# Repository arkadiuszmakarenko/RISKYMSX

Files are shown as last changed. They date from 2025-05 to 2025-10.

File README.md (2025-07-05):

# RISKYMSX

The RISKYMSX cartridge by Arkadiusz Makarenko is a compact MSX flash ROM cartridge based on the inexpensive CH32V30xVCT6 RISC-V MCU which can be easily programmed from a MSX computer using a FAT formatted USB pen drive containing ROM files.

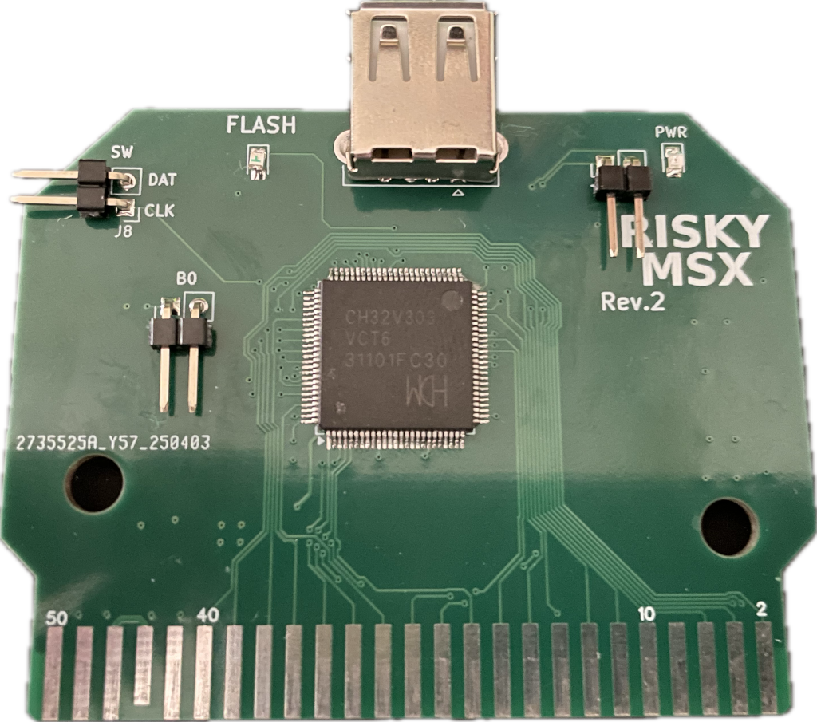
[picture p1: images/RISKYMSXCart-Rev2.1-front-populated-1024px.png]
[](images/RISKYMSXCart-Rev2.1-front-populated-1024px.png)

## Main Features

* Support for up to 256KB ROMs
* SCC emulation
* Firmware updates using a USB-A cable (or alternatively a WCH-LinkE programmer)
* ROM Flashing:
  * No external flash programmer is needed
  * A ROM can be flashed in-system using a MSX computer and a FAT-formatted USB pen drive
  * `ROM Flashing Mode` is activated by pressing GRAPH key during MSX boot
  * Automatic flashing of ROMs from USB can be achieved via specially named ROM archives
  * Manually flashing of ROMs from USB is done using a simple interactive menu
  * FAT long filenames are supported
* Supported mappers:
  * Standard 16KB ROMs
  * Standard 32KB ROMs
  * Standard 48KB /64KB ROMs
  * KONAMI without SSC
  * KONAMI with SSC (EN - SCC emulation enabled)
  * KONAMI with SSC (DIS - SCC emulation disabled)
  * ASCII 8K
  * ASCII 16K
  * Neo 8k
  * Neo 16k

## Hardware

The RISKYMSX cartridge is made up of a 4-layer PCB with a reduced set of SMD components and through-hole connectors:
* A WCH [CH32V303VCT6](https://www.wch-ic.com/products/CH32V303.html) MCU (or alternatively a [CH32V307VCT6](https://www.wch-ic.com/products/CH32V307.html))
* Two LEDs, one to indicate power on state, and one lit during `ROM Flashing Mode`
* A [LM1117](https://www.ti.com/lit/ds/symlink/lm1117.pdf) voltage regulator to provide +3V3 to the MCU from the +5V rail of the MSX cartridge slot
* A [MCP6001](https://ww1.microchip.com/downloads/aemDocuments/documents/MSLD/ProductDocuments/DataSheets/MCP6001-1R-1U-2-4-1-MHz-Low-Power-Op-Amp-DS20001733L.pdf) operational amplifier to enhance the SCC audio signal fed into the MSX cartridge SOUNDIN pin
* Three headers:
  * B0: open by default, closed only while programming the MCU using the `WCHISPTool_CMD` tool
  * DAT/CLK: unconnected by default, used to program the MCU using the [`WCH-LinkE`](https://www.wch-ic.com/products/WCH-Link.html) programmer via SWDIO/SWCLK
  * RX/TX: unconnected by default, serial debug console
* One USB Type-A female connector
* Several passives required for proper operation of the above components

### Revisions

There are several hardware revisions of the cartridge. The main ones are listed here in reverse chronological order.

#### Rev 2.1 (current)

This version introduces the following changes:
* the flash button is removed, as the flashing interface can be accessed by pressing the GRAPH key on the MSX keyboard during boot
* unnecessary leds are removed, leaving just the Flash and Power leds
* the audio amplifier circuit is enhanced with a low pass filter 

See the [Bill Of Materials (BoM)](https://html-preview.github.io/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) generated from the KiCad files for information about the specific components used.

Have a look at the [schematic and PCB](https://kicanvas.org/?github=https%3A%2F%2Fgithub.com%2Farkadiuszmakarenko%2FRISKYMSX%2Ftree%2Fmain%2Fboard) using [KiCanvas](https://kicanvas.org).

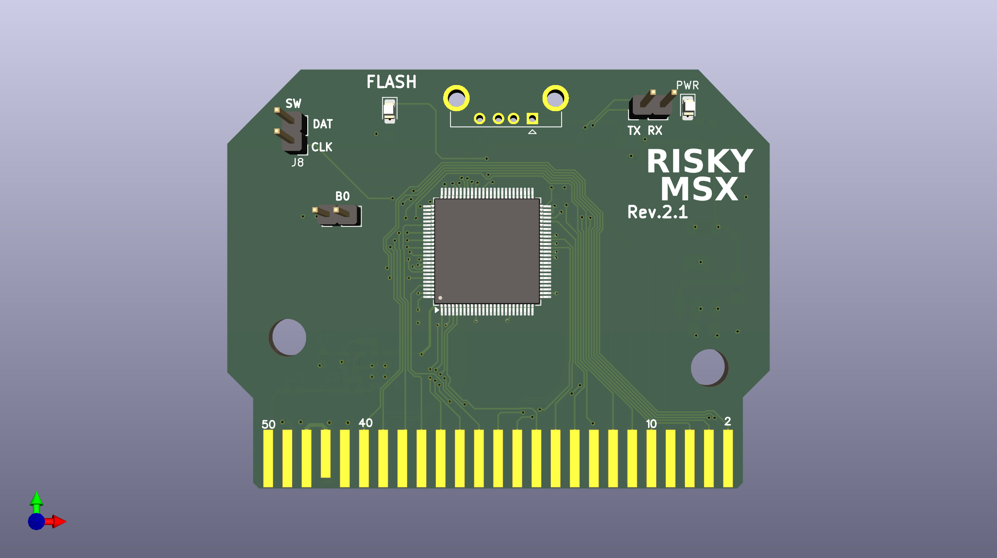
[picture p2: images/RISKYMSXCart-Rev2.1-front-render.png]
[](images/RISKYMSXCart-Rev2.1-front-render.png)
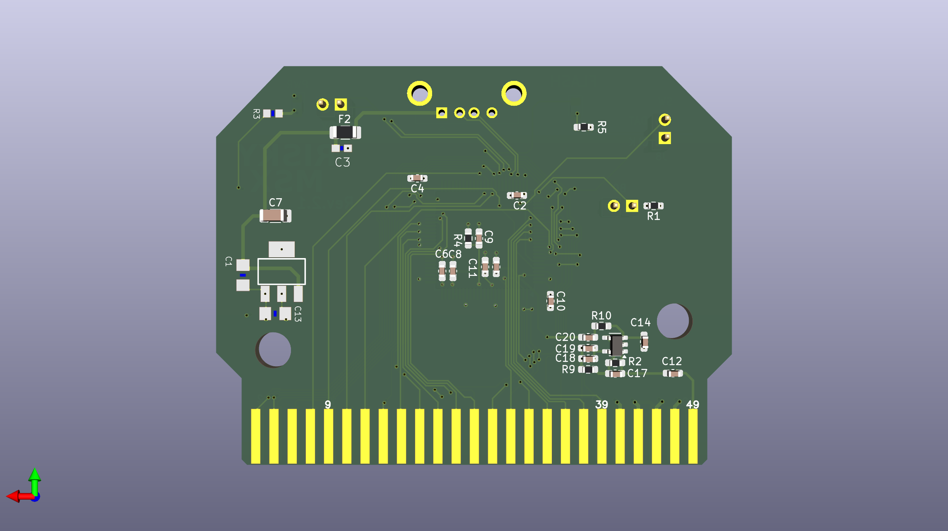
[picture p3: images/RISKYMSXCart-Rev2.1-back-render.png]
[](images/images/RISKYMSXCart-Rev2.1-back-render.png)

#### Rev 2 (obsolete)

This version introduces the following changes:
* the LM1117 voltage regulator and related passives are moved to the back of the PCB
* the B1 header is removed as it has no practical use
* a simple audio amplifier circuit is added for SCC sound

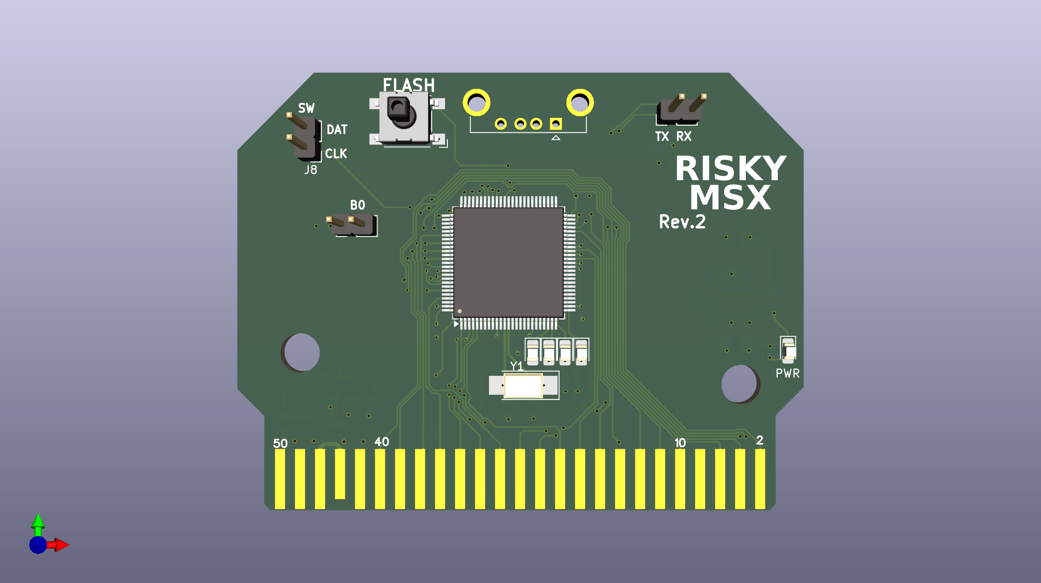
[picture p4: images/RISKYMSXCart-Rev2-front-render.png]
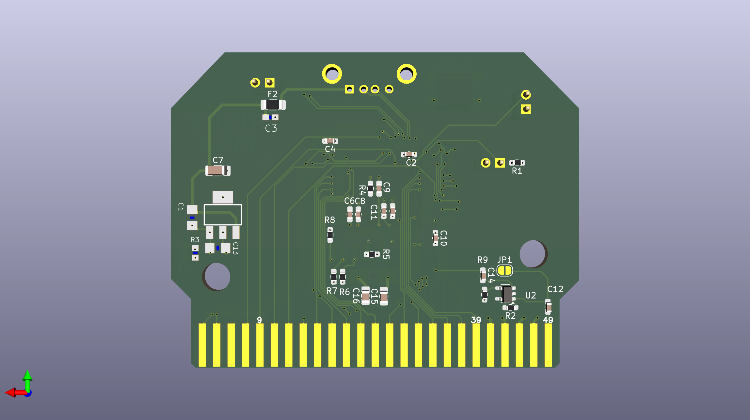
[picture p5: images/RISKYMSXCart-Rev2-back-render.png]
[](images/RISKYMSXCart-Rev2-front-render.png)|[](images/RISKYMSXCart-Rev2-back-render.png)
|-|-|
|RISKYMSX Rev 2 front render|RISKYMSX Rev 2 rear render|

#### Rev 1 (obsolete)

This is the initial revision of the RISKYMSX cartridge.

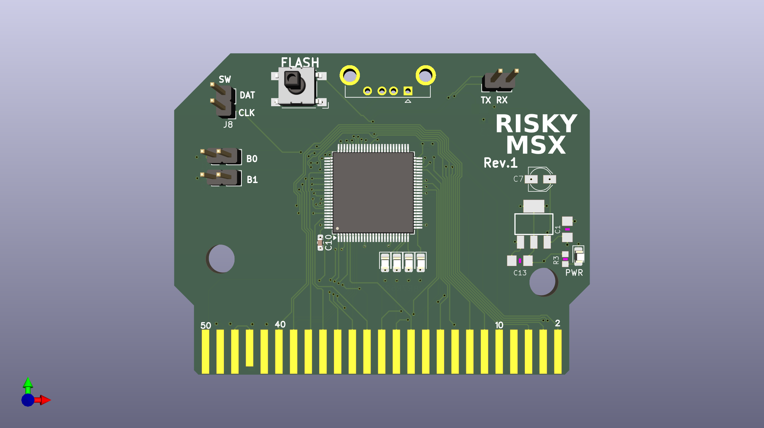
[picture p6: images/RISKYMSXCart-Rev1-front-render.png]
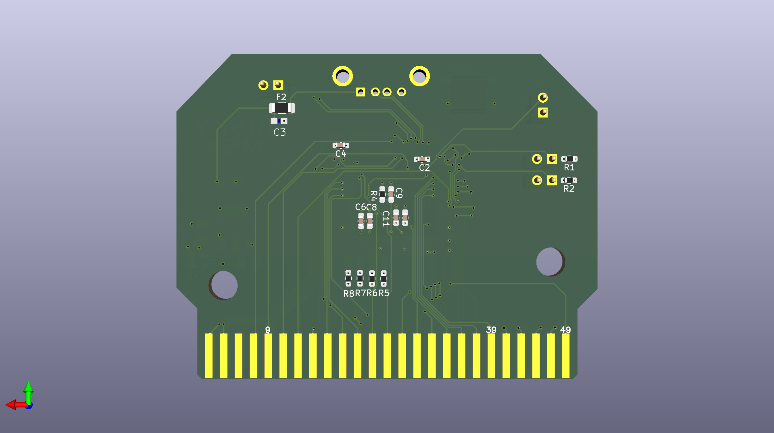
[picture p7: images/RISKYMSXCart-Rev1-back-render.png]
[](images/RISKYMSXCart-Rev1-front-render.png)|[](images/RISKYMSXCart-Rev1-back-render.png)
|-|-|
|RISKYMSX Rev 1 front render|RISKYMSX Rev 1 rear render|

## Firmware

The firmware implements two different modes of operation for the RISKYMSX cartridge:
* `Normal Mode`. In this mode a ROM cartridge is emulated according to the last ROM flashed using the `ROM Flashing Mode`.
* `ROM Flashing Mode`. In this mode a ROM can be flashed manually or automatically into the cartridge by using a FAT formatted USB pen drive.

## Building a RISKYMSX cartridge

You will need good soldering skills and specific equipment to build a RISKYMSX cartridge.
As you probably saw on the Bill Of Materials, there are quite small SMD components like 0603 passives and a LQFP-100 package with 0.5mm pitch that need to be soldered.

> [!WARNING]
> If you are building new boards, please use the current available board revision.

### PCB

The PCB can be fabricated by your favorite PCB manufacturer from the [supplied gerber files](https://github.com/arkadiuszmakarenko/RISKYMSX/blob/main/RiskyMSXv21PCB.zip).

### Suggested tools

These are example tools used during the manual building of the RISKYMSX cartridge:

* silicone heat-resistant mat (TE-616 400x290mm), to avoid burning your precious desk
* electronic microscope with 2 LEDs (KKmoon 3" LCD 10X-300X 3.0MP 1080P HDMI electronic digital video microscope), to be able to solder those small 0.5mm pitch pins
* temperature controlled soldering station (Yihua 908D), to make good soldering joints
* T-1C "horseshoe", T-I and T-1.6D soldering tips (900M series), use the best fitting one for each soldering job
* copper sponge, for soldering head cleaning
* flux (Mechanic UV80 flux paste), to help keep components in place and achieve good soldering joints
* solder (0.5mm, for hobby projects you may use 60% Sn / 40% Pb Flux 2% at your own risk)
* desoldering wick (2.5mm is fine), for correcting mistakes if you are human)

### Component shopping list

> [!WARNING]
> Aliexpress links may not work, as sellers come and go.

| **ref** | **component**  | **req_pcs** | **item_description** | **item_option** | **pcs_per_item** | **req_items** | **link** |
| --- | --- | --- | --- | --- | --- | --- | --- |
| C2, C4, C5, C6, C7, C8, C9, C10, C11, C19 | 0603 100nF | 10 | 100pcs 0603 SMD Chip Multilayer Ceramic Capacitor 0.5pF - 22uF 10pF 22pF 100pF 1nF 10nF 15nF 100nF 0.1uF 1uF 2.2uF 4.7uF 10uF | 0603 100nF 50V | 100 | 1 | [aliexpress](https://aliexpress.com/item/32966526545.html) |
| C18 | 0603 1uF | 1 | 100pcs 0603 SMD Chip Multilayer Ceramic Capacitor 0.5pF - 22uF 10pF 22pF 100pF 1nF 10nF 15nF 100nF 0.1uF 1uF 2.2uF 4.7uF 10uF | 0603 1uF 25V | 100 | 1 | [aliexpress](https://aliexpress.com/item/32966526545.html) |
| C12, C20 | 0603 4.7uF | 2 | 100pcs 0603 SMD Chip Multilayer Ceramic Capacitor 0.5pF - 22uF 10pF 22pF 100pF 1nF 10nF 15nF 100nF 0.1uF 1uF 2.2uF 4.7uF 10uF | 0603 4.7uF 10V | 100 | 1 | [aliexpress](https://aliexpress.com/item/32966526545.html) |
| C3 | 0603 10uF | 1 | 100pcs 0603 SMD Chip Multilayer Ceramic Capacitor 0.5pF - 22uF 10pF 22pF 100pF 1nF 10nF 15nF 100nF 0.1uF 1uF 2.2uF 4.7uF 10uF | 0603 10uF 10V | 100 | 1 | [aliexpress](https://aliexpress.com/item/32966526545.html) |
| C1 | 1206 100nF | 1 | 100pcs 1206 SMD Chip Multilayer Ceramic Capacitor 0.5pF - 100uF 10pF 100pF 1nF 10nF 15nF 100nF 0.1uF 1uF 2.2uF 4.7uF 10uF 47uF | 1206 100nF 50V | 100 | 1 | [aliexpress](https://aliexpress.com/item/32966490820.html) |
| C13 | 1206 1uF | 1 | 100pcs 1206 SMD Chip Multilayer Ceramic Capacitor 0.5pF - 100uF 10pF 100pF 1nF 10nF 15nF 100nF 0.1uF 1uF 2.2uF 4.7uF 10uF 47uF | 1206 1uF 25V | 100 | 1 | [aliexpress](https://aliexpress.com/item/32966490820.html) |
| R1, R2, R4, R9, R10 | 0603 10K | 5 | 100PCS 0603 1% SMD resistor 0R ~ 10M 1/10W 0 1 10 100 150 220 330 470 ohm 1K 2.2K 10K 100K 1M 0R 1R 10R 100R 150R 220R 330R 470R | 10K | 100 | 1 | [aliexpress](https://aliexpress.com/item/1005005677654015.html) |
| R3, R5 | 0603 220 | 2 | 100PCS 0603 1% SMD resistor 0R ~ 10M 1/10W 0 1 10 100 150 220 330 470 ohm 1K 2.2K 10K 100K 1M 0R 1R 10R 100R 150R 220R 330R 470R | 220R | 100 | 1 | [aliexpress](https://aliexpress.com/item/1005005677654015.html) |
| D1 | 0805 green LED | 1 | 5 colors x20pcs =100pcs SMD 0805 led kit Red/Green/Blue/Yellow/White LED Light Diode Free Shipping! KIT | n/a | 20 | 1 | [aliexpress](https://aliexpress.com/item/32288211535.html) |
| D5 | 0805 red LED | 1 | 5 colors x20pcs =100pcs SMD 0805 led kit Red/Green/Blue/Yellow/White LED Light Diode Free Shipping! KIT | n/a | 20 | 0 | |
| U1 | CH32V307VCT6 | 1 | 1-50Pcs New CH32V303VCT6 CH32V303 VCT6 CH32V LQFP-100 Microcontroller IC Chip In Stock Wholesale | 2Pcs CH32V303VCT6 | 2 | 1 | [aliexpress](https://aliexpress.com/item/1005006687185523.html) |
| U2 | MCP6001-OT | 1 | 20PCS 100% New MCP6001T-I/OT SOT23-5 MCP6001T-I SOT23 MCP6001 SMD MCP6001T Chipset | n/a | 20 | 1 | [aliexpress](https://aliexpress.com/item/1005006809254782.html) |
| F2 | 3216 0.5A | 1 | 3216 1206 0.05A 0.1A 0.12A 0.16A 0.2A 0.25A 0.5A 0.75A 1.1A 2A SMD Resettable Fuse PPTC PolySwitch Self-Recovery Fuse | 500MA, 1206, 20 Pcs  | 20 | 1 | [aliexpress](https://aliexpress.com/item/1005004273302126.html) |
| IC8 | LM1117MPX-3.3  | 1 | 5PCs LM1117MPX-1.8 N12A LM1117MPX-2.5 N13A LM1117MPX-3.3 N05A/B LM1117MPX-5.0 N06A LM1117MPX-AJ N03A SOT-223 Linear Regulator | LM1117MPX-3.3 | 5 | 1 | [aliexpress](https://aliexpress.com/item/1005007393149096.html) |
| J1, J2, J8 | Conn_01x02 | 1 | 10pcs 40 Pin 1x40 Single Row Male and Female 2.54 Breakable Pin Header PCB JST Connector Strip for arduino DIY Kit | Male Color 2pcs each | 10 | 1 | [aliexpress](https://aliexpress.com/item/1005007324368709.html) |
| J7 | USB_1 | 1 | Hot Sale USB Type A Standard Port Female Solder Jacks Connector PCB Socket Type B 90 Degree Horizontal Straight Insertion Patch  | 10PCS USB-02 | 10 | 1 | [aliexpress](https://aliexpress.com/item/1005005865561469.html) |

Beware of fake chips and components:
* If you receive MCP6001 op-amps marked as SA10, they are probably MCP601 op-amps.
* MCP6001 op-amps marked as AAYS should be fine.
* LM1117MPX-3.3 voltage regulators marked as N05A should be fine.

### Assembling the hardware

The central piece of the cartridge is the CH32V30xVCT6 MCU which is at the same time the most difficult element to solder.

You can solder components in the following suggested order, or do as you feel comfortable:
* U1 CH32V30xVCT6
* D1,D5 leds
* F2 fuse
* R3, R5 led resistors
* R1 boot0 pull-down resistor
* IC8 LM1117MPX-3.3
* C3 10uF capacitor
* C7 and C1 100nF capacitors
* C13 1uF capacitor
* C4, C2, C6, C8, C5, C11 and C10 100nF capacitors
* R4 and C9 do not need to be populated (confirmation needed)
* U2 MCP6001-OT op-amp
* C12 and C20 capacitors
* C19 capacitor
* C18 capacitor
* R10, R9 and R2 resistors
* C14 and C17 capacitors

> [!WARNING]
> C5 is not marked on the PCB, it is the capacitor to the right of the C11 marking (C11 mark is closer to C5 than to C11)
>
> C11 is the capacitor to the right of the C5 capacitor

### Building the firmware on Linux

> [!NOTE]
> These instructions have been validated using Ubuntu 24.04.2 LTS.

#### Cloning the RISKYMSX github repository

```bash
cd $HOME
git clone 'https://github.com/arkadiuszmakarenko/RISKYMSX.git'
```

This will clone the RISKYMSX github repository to the `RISKYMSX` directory under your home directory.

#### Installing the [MounRiverStudio IDE](http://www.mounriver.com)

1. Download the MounRiverStudio package for Linux

[http://www.mounriver.com/download](http://www.mounriver.com/download)

Choose the package in `tar.xz` format.

2. Uncompress the MounRiverStudio package into a known directory

For example this will uncompress the MounRiverStudio package into the IDE directory under your home directory.

```bash
export IDEDIR=$HOME/IDE
mkdir -p $IDEDIR && cd $IDEDIR
tar xJvf /path/to/MounRiverStudio_Linux_X64_V210.tar.xz
```

Once uncompressed, all package files are under the `MRS2` directory.

3. Setup the MounRiverStudio

You can follow the instructions described on the `README` file.
Alternatively, if you don't want to install library files system-wide you can follow these instructions:

* Change to the `MRS2/beforeinstall` directory

```bash
cd MRS2/beforeinstall
```

* Make a backup of the `start.sh` script file for reference

```bash
cp start.sh start.sh.orig
```

* Modify the `start.sh` script file.

Comment out the lines that install libraries and the line that gives world write access to all files under the `MRS-linux-x64` directory.
Leave as is the code that copies the udev rules for the WCH programmers and reloads them into udevadm.

```bash
#! /bin/bash
#echo  -e "\nCopy Libs"
#sudo cp -P ./lib*    /usr/lib
#echo  -e "Register new Libs"
#sudo ldconfig
echo "copy rules"
sudo cp ./50-wch.rules /etc/udev/rules.d
sudo cp ./60-openocd.rules  /etc/udev/rules.d
echo "Reload rules"
sudo udevadm control  --reload-rules

#chmod -R 777 ../MRS-linux-x64
chmod -R 750 ../MRS-linux-x64

echo -e "DONE"
```

* Run the modified `start.sh` script

```bash
chmod u+x start.sh
./start.sh
```

* Make the `chrome-sandbox` executable suid to root by changing the ownership of the file to root and setting the SUID bit.

This is required as the MounRiverStudio IDE is an Electron-based application that uses a sandbox approach.

```bash
cd ../MRS-linux-x64
sudo chown root chrome-sandbox
sudo chmod 4755 chrome-sandbox
```

#### Launching the MounRiverStudio IDE

If you installed the MounRiverStudio IDE under `$HOME/IDE`, use the following complete command line whenever you need to launch MounRiverStudio IDE specifying where to find the extra libraries needed.

```bash
cd $HOME/IDE/MRS2/MRS-linux-x64
LD_LIBRARY_PATH=$(readlink -f ../beforeinstall/) ./mounriver-studio\ 2
```

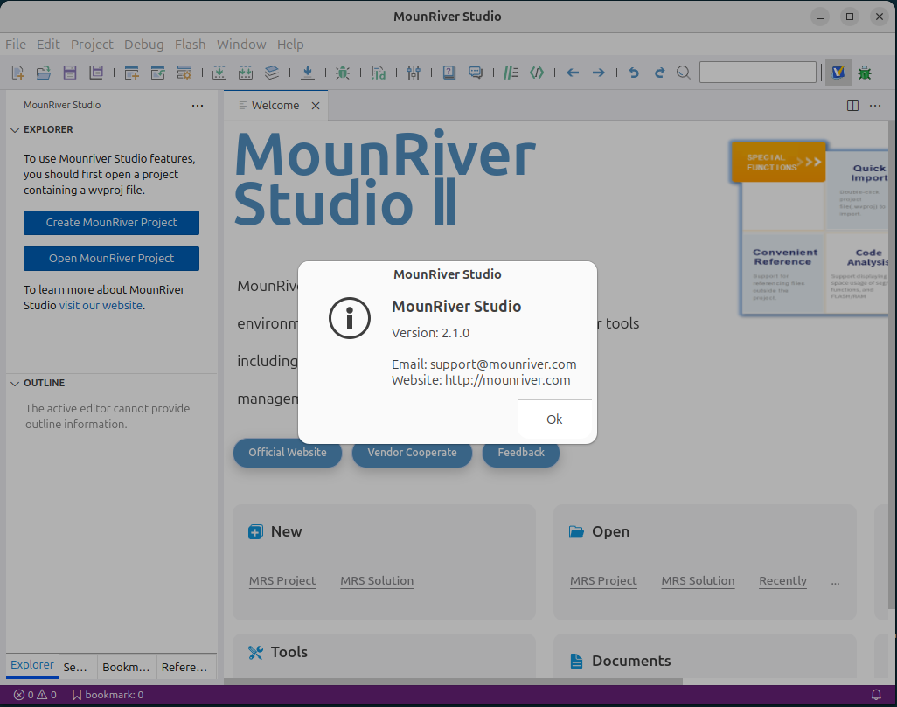
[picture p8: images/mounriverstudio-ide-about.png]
[](images/mounriverstudio-ide-about.png)

#### Generating the firmware file

1. After launching the MounRiverStudio IDE, open the RISKYMSXCART project file

`File | Open MounRiver Project`

**`/path/to/your/RISKYMSX/firmware/RISKYMSXCART.wvproj`**

The project file is under the `firmware` directory on the cloned github repository.

2. Build the project

`Project | Build Project`

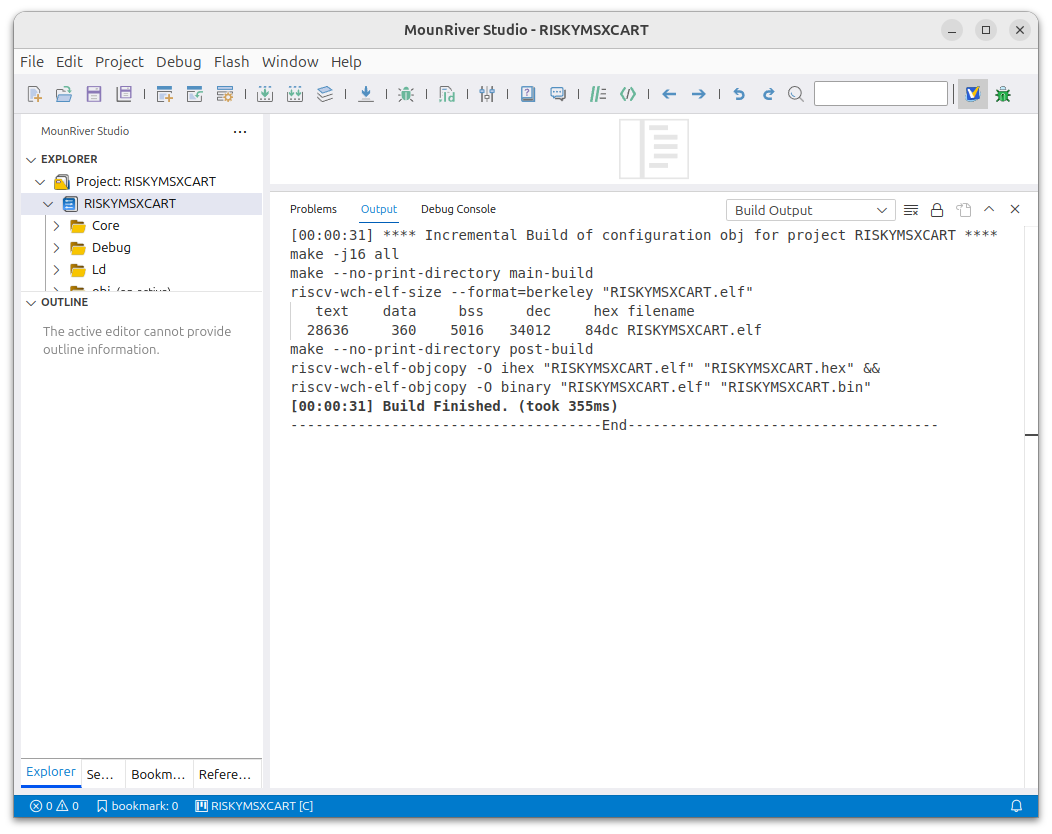
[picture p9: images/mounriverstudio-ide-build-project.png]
[](images/mounriverstudio-ide-build-project.png)

#### Programming the firmware

The firmware can be programmed into the RISKYMSX cartridge using the MounRiverStudio IDE and a WCH-LinkE programmer, or using the WCHISPTool_CMD and a USB Type A to Type A cable.

> [!NOTE]
> It has been observed that the WCH-LinkE programmer method is more reliable than the WCHISPTool_CMD method when flashing a chip for the first time.
It is recommended to use WCH-LinkE for initial firmware programming,  there is a lot of reports that programming initial firmware over USB is very unreliable. Upgrading existing firmware using this method works well.

Choose the option that better suits you.

##### Programming the firmware using the WCH-LinkE programmer

Using the WCH-LinkE allows to program a .HEX firmware file to the CH32V30xVCT6.

1. Connect the WCH-LinkE programmer and RISKYMSX cartridge

  * Make sure the RISKYMSX cartridge is _disconnected_ from the MSX.

  * Using two dupont wires, connect the WCH-LinkE programmer to the RISKYMSX cartridge.

    You need to perform specifically the following connections:
    * the SWCLK/TCK pin of the WCH-LinkE programmer to the CLK pin of the J8 header of the RISKYMSX cartridge
    * the SWDIO/TMS pin of the WCH-LinkE programmer to the DAT pin of the J8 header of the RISKYMSX cartridge

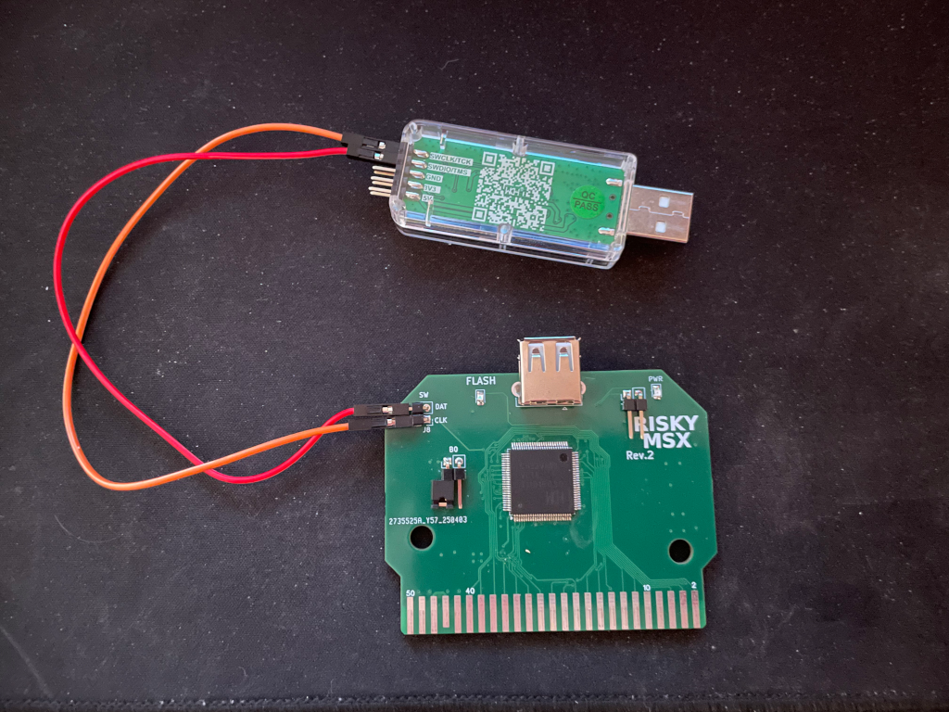
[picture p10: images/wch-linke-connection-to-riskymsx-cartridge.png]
[](images/wch-linke-connection-to-riskymsx-cartridge.png)

* Connect the USB port of the RISKYMSX cartridge to a free USB port of the computer running the MounRiverStudio software.

You will need a USB Type A end on the RISKYMSX cartridge and the appropriate USB end on your computer.

This USB connection will be used just to power the CH32V30xVCT6.
After the connection is made, the RISKYMSX cartridge should lit the power led PWR on.

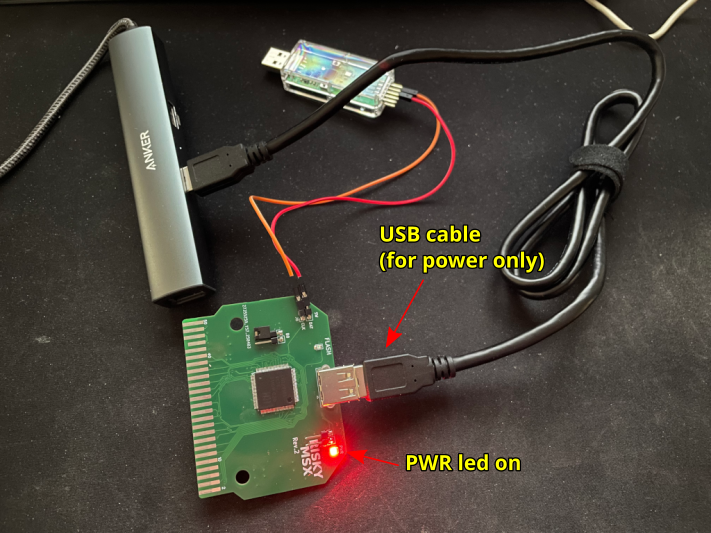
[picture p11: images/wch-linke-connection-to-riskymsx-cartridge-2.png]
[](images/wch-linke-connection-to-riskymsx-cartridge-2.png)

* Connect the WCH-LinkE programmer to the computer running the MounRiverStudio IDE on a free USB Type A port.

Once connected, the WCH-LinkE should lit the red led on and the blue led off to indicate operation in RISC-V mode.

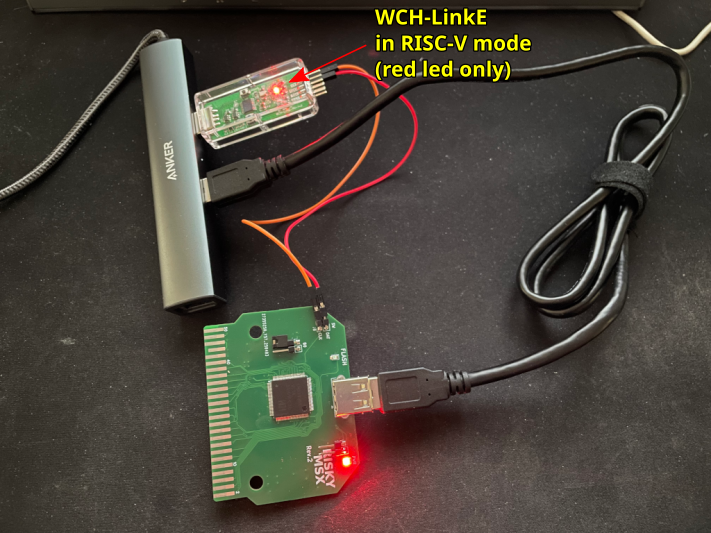
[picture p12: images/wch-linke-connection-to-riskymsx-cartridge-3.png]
[](images/wch-linke-connection-to-riskymsx-cartridge-3.png)

If the WCH-LinkE shows any other led combination, you should follow the [WCH-LinkE manual](https://www.wch-ic.com/downloads/WCH-LinkUserManual_PDF.html) to put your WCH-LinkE in RISC-V mode.

One simple way to switch to RISC-V mode is to press and hold the ModeS button while connecting the WCH-LinkE programmer.
Note that on some WCH-LinkE programmers the plastic enclosure does not allow access to the ModeS button and you will need to either remove the enclosure to access the ModeS button or use the MounRiverStudio software to switch to RISC-V mode by software.

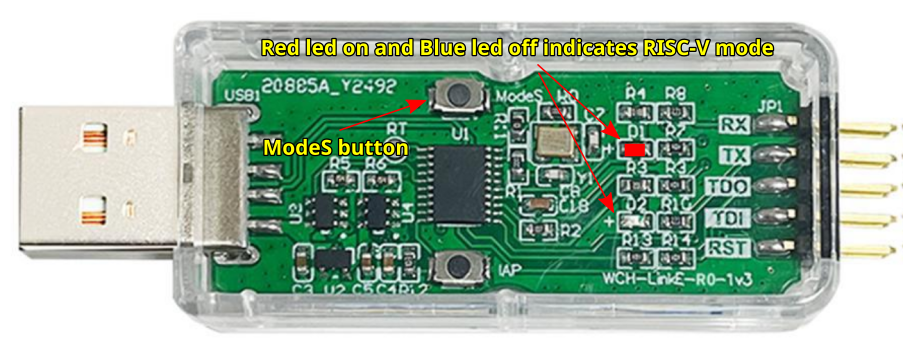
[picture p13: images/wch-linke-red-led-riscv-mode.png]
[](images/wch-linke-red-led-riscv-mode.png)

2. Launch the MounRiverStudio IDE and open the Download preferences to specify the memory assignment settings and location of the target file

`Flash | Download Configuration`

`Download Settings`

`MCU Memory Assign: ` **`288K ROM + 32K RAM`**

`Target File : `**`/path/to/your/RISKYMSX/firmware/obj/RISKYMSXCART.hex`**

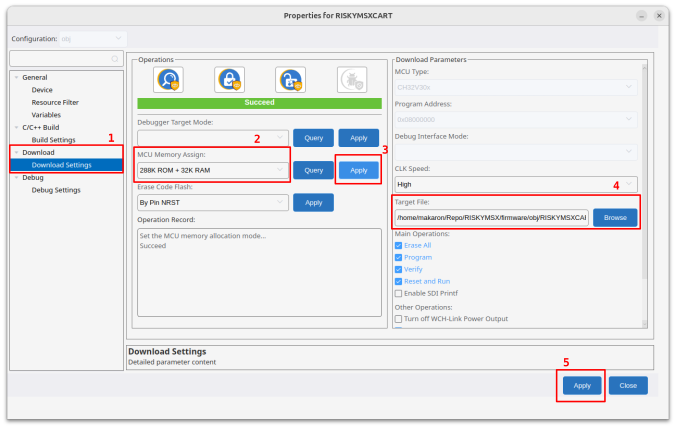
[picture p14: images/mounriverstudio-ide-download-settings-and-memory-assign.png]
[](images/mounriverstudio-ide-download-settings-and-memory-assign.png)

3. Proceed with the firmware download to the RISKYMSX cartridge

`Flash | Download`

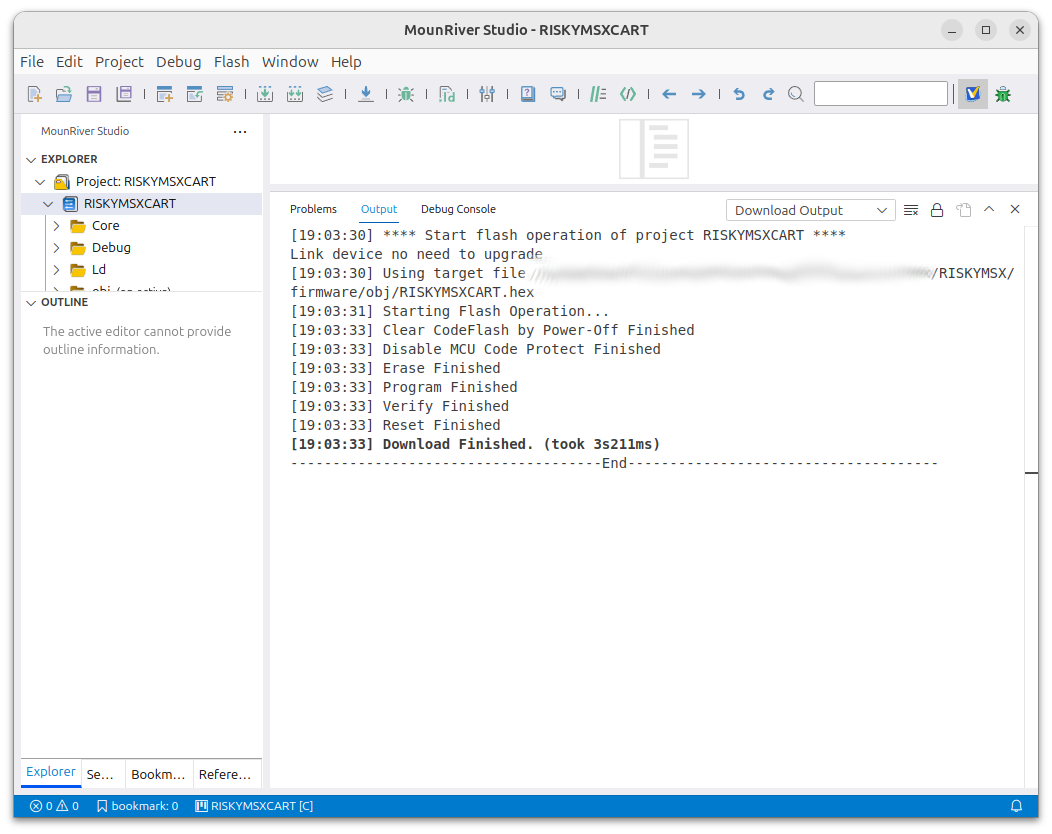
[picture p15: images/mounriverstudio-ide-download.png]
[](images/mounriverstudio-ide-download.png)

If you receive an error, try power cycling the RISKYMSX cartridge by disconnecting and reconnecting the USB cable from the RISKYMSX cartridge, and then retry the operation.

##### Programming the firmware using the WCHISPTool_CMD tool

Using the WCH-LinkE allows to program a .BIN firmware file to the CH32V30xVCT6.

1. If you haven't done it yet, download and uncompress the WCHISPTool_CMD archive

* Download the [WCHISPTool_CMD](https://www.wch-ic.com/downloads/WCHISPTool_CMD_ZIP.html)

* Uncompress the `WCHISPTool_CMD.ZIP` archive

```bash
unzip WCHISPTool_CMD.ZIP
```

Once uncompressed all package files are under the `WCHISPTool_CMD/` directory.

* Make sure the `WCHISPTool_CMD` tool is executable

```bash
chmod u+x WCHISPTool_CMD/Linux/bin/x64/WCHISPTool_CMD
```

This will make the tool binary for x64 processors executable by the current user.

2. Build the required Linux kernel module

The mentioned Linux kernel mode is used to talk to the ISP interface of the CH32V30xVCT6 chip.

You will need to build the kernel module everytime you upgrade your kernel, otherwise the kernel module will not load because of the mismatch between kernel and module.

```bash
cd WCHISPTool_CMD/Linux/driver/
make clean
make
```

Note that you are not required to run `make install` to install the kernel module if you just want to use the tool sparingly.

3. Load the compiled kernel module into the running kernel

```bash
sudo insmod ch37x.ko
```

4. Close the B0 header pins using a 2.54" jumper.

By closing the B0 header, the CH32V30xVCT6 MCU will enter ISP programming mode once powered on.

5. Connect the RISKYMSX cartridge to your computer using a USB cable.

The required USB cable needs a Type A male termination on one side to connect to the RISKYMSX cartridge, and another USB male connector suitable for your computer on the other end.
If your computer has USB Type A ports, a USB Type A to USB Type A cable should be fine.

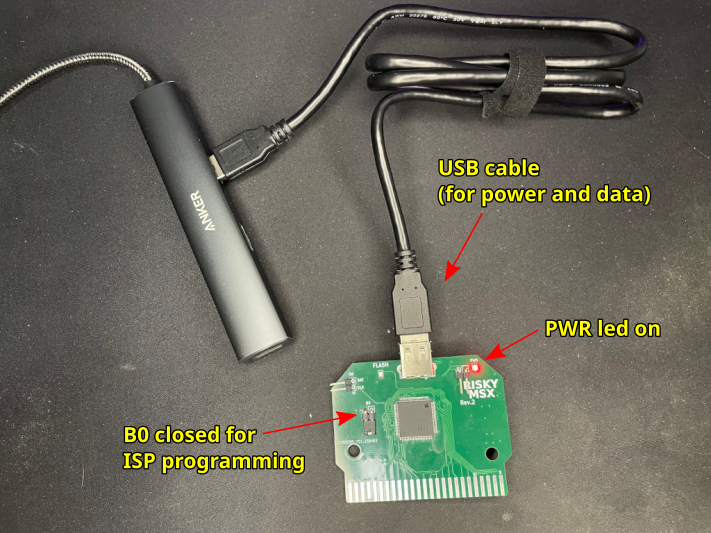
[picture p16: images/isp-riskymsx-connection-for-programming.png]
[](images/isp-riskymsx-connection-for-programming.png)

6. Check that the device node for the CH32V30xVCT6 in ISP programming node appears on your system

```bash
ls -la /dev/ch3*
```
```
crw------- 1 root root 180, 2 Jun  3 15:58 /dev/ch37x2
```

6. Run the `WCHISPTool_CMD` tool to program the RISKYMSX cartridge firmware

The following command assumes that both the `WCHISPTool_CMD` and `RISKYMSX` github repository directories are available under the current working directory, and that the RISKYMSX firmware binary file has been copied to the current directory under the name `RISKYMSXCART.bin`.

```bash
sudo WCHISPTool_CMD/Linux/bin/x64/WCHISPTool_CMD -p /dev/ch37x2 -f RISKYMSXCART.bin -o program -c RISKYMSX/prog/CONFIG.INI -r 1
```

where:
* `/dev/ch37x2` is the device node for your CH32V30x as it appears on your system
* `RISKYMSXCART.bin` is the firmware binary file provided in the github repository (or the one built by you if you rebuilt the project)
* `RISKYMSX/prog/CONFIG.INI` is the configuration file for the `WCHISPTool_CMD` also provided in the github repository

When the programming completes successfully you will see an output similar to this one:

```
=====ISP_Command_Tool=====

TOOL VERSION:  V3.70

p:/dev/ch37x2
b:0
v:0
c:RISKYMSX/prog/CONFIG.INI
o:0
f:RISKYMSXCART.bin
r:1

{"Device":"/dev/ch37x2","Status":"Ready"}
{"Device":"/dev/ch37x2", "Status":"Programming", "Progress":100%} 
{"Device":/dev/ch37x2", "Status":"Finished", "Code":0,"Message":"Succeed"}
```

### Building the firmware on Windows

TBE

#### Programming the firmware

You need WCHISPTool from https://wch-ic.com/ website.

##### USB A - USB A Cable or Serial adapter
 * Close jumper B0.
 * Connect RISKY MSX to PC using USB A to USB A cable or serial.
 * For USB A Cable Dnld Port should change to USB.
 * For serial select your serial device COM
 * Select Chip Series - CH32V30x
 * Chip Model : CH32V303VCT6
 * Select Object File1 and pick up firmware .bin.
 * Under Chip Config select Chip Memory Allocation RAMX 32KB + ROM 288KB
 * Click Deprotect
 * Click Download

## Cartridge Operation

The RISKYMSX cartridge can operate in two different modes once programmed with the RISKYMSX firmware.

Make sure the MSX computer is powered off before inserting or removing the RISKYMSX cartridge or any other cartridge.

> [!WARNING]
> All cartridge headers (B0, DAT/CLK and RX/TX) must be unconnected for cartridge operation when inserted into a MSX computer.

### Normal Mode

In `Normal mode` the RISKYMSX cartridge behaves as a ROM cartridge once a ROM has been flashed.

Just insert the RISKYMSX cartridge and enjoy the already flashed ROM.

### ROM Flashing Mode

In `ROM Flashing Mode` a ROM file residing in a USB drive can be flashed to the RISKYMSX cartridge for later use in `Normal Mode`.

1. Make sure the MSX computer is powered off

2. Insert the RISKYMSX cartridge

3. Press and hold the `GRAPH` key on the MSX computer keyboard and power on the MSX computer.

You can release the `GRAPH` key once you see the Flash LED turn on.

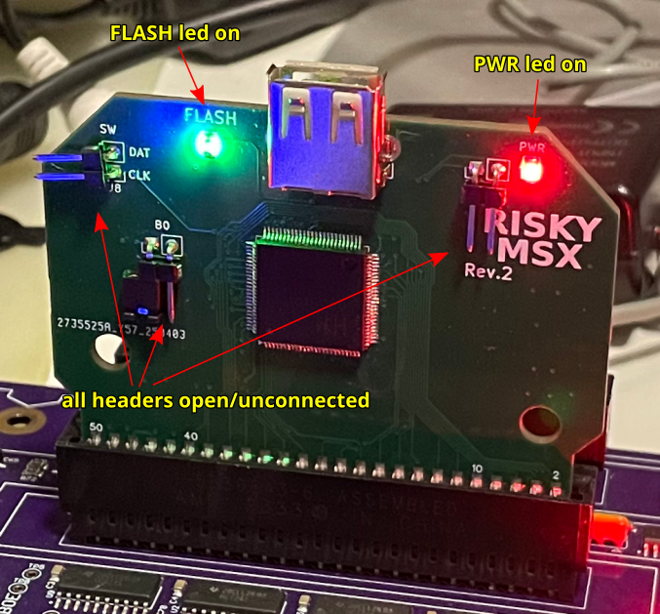
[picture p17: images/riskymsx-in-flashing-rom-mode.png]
[](images/riskymsx-in-flashing-rom-mode.png)

4. If no USB drive is connected to the RISKYMSX cartridge, the "Insert USB" screen will appear.

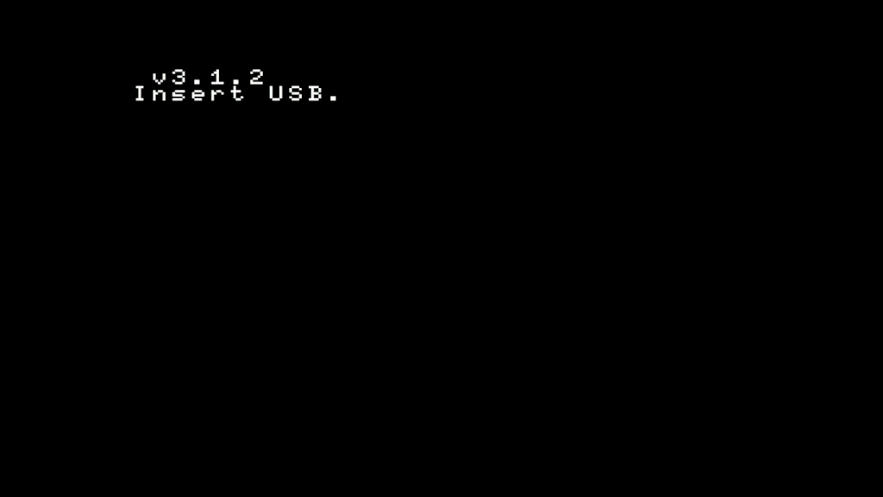
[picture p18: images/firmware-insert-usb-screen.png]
[](images/firmware-insert-usb-screen.png)

You will need to connect a FAT-formatted USB drive to continue the ROM flashing procedure.

Once that is done, the RISKYMSX will try first to auto-flash a ROM before switching to manually flashing ROMs.

#### Auto-flashing ROMs

The RISKYMSX firmware will automatically flash the first file found on the root directory of the connected FAT-formatted USB drive matching one of the special filenames for ROM auto-flashing, according to the following table. A mapper will be automatically assigned based on the filename detected.

 | Mapper               | filename         | 
 |   :-----------:      | :--------------: | 
 | 16KB ROM             | cart.r16         | 
 | 32KB ROM             | cart.r32         | 
 | KONAMI without SSC   | cart.ko4         | 
 | KONAMI with SSC(EN)  | cart.ko5         | 
 | KONAMI with SSC(DIS) | cart.kd5         | 
 | ASCII8k              | cart.a8k         | 
 | ASCII16k             | cart.a16         | 
 | NEO16                | cart.n16         | 
 | NEO8                 | cart.n8k         | 

So for example, to automatically flash F1SPIRIT.ROM, which is a KONAMI with SCC game, the F1SPIRIT.ROM file can be copied to the root of the USB drive using the filename **cart.ko5**, and then follow the mentioned procedure.

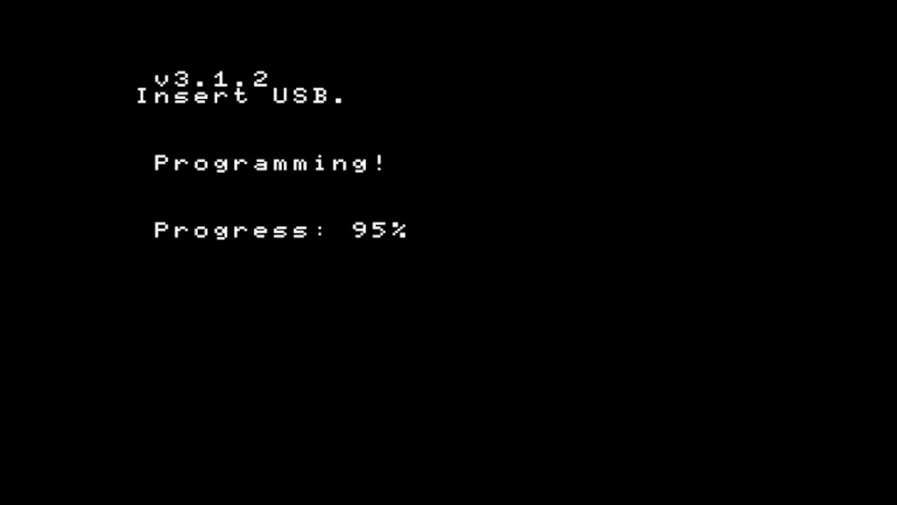
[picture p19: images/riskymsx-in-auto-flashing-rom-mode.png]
[](images/riskymsx-in-auto-flashing-rom-mode.png)

After flashing the ROM file, the RISKYMSX will automatically reboot the MSX computer and the ROM will load.

Note that if several files matching the auto-flashing filenames are found on the USB drive, only the file that causes the first match in the above table order will be flashed.

#### Manually flashing ROMs

If the connected FAT-formatted USB drive contains no files matching the auto-flashing filenames, the RISKYMSX firmware will display the interactive ROM flashing menu.

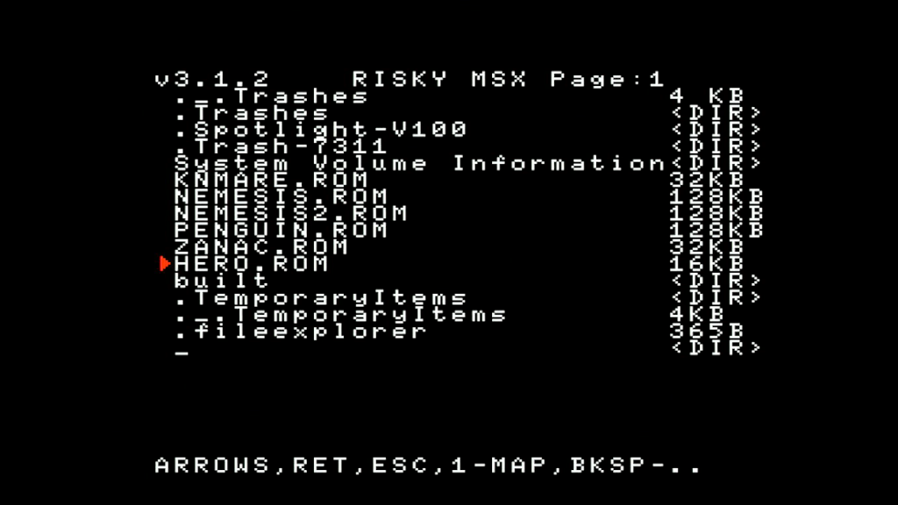
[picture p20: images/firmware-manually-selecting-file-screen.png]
[](images/firmware-manually-selecting-file-screen.png)

Use the following keys to interact with the file menu screen:
* `Up`, `Down`: move up or down the red arrow cursor across the available files in the current page
* `Right`: go to the next page (if more files are available to list)
* `Left`: go to the previous page (if any pagination was done before)
* `Return`: select a file for flashing
* `Esc`: go to the previous screen, or reload the file list on the root directory
* `1`: show the current flashed ROM file and mapper type, and optionally change the mapper type
* `Backspace`: go to the previous directory level on the file manu

Useful tips:
* The bottom of the file menu screen shows the keys that are available to use at any moment
* You can always hot-swap the USB drive while in the file menu, and once a new USB drive is connected you need to press `Esc` to refresh the file contents
* DO NOT navigate or select files while you have disconnected a USB drive without pressing `Esc` first
* If you flash a ROM with the wrong mapper type, you can change the mapper type easily, without reflashing the ROM again, by pressing `1`

When a ROM file is selected by pressing the `Return` key the mapper selection screen shows up.

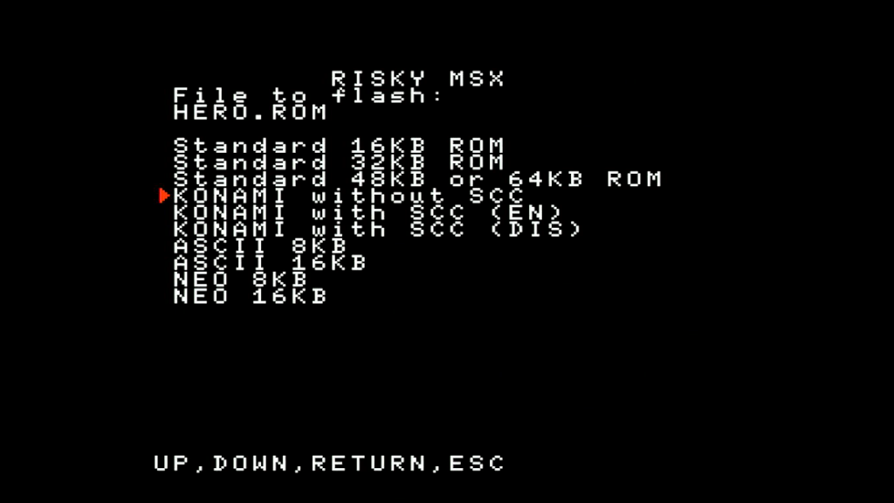
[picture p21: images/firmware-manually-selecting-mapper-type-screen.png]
[](images/firmware-manually-selecting-mapper-type-screen.png)

Select the correct mapper type for the selected ROM file and press `Return` to start flashing the ROM.

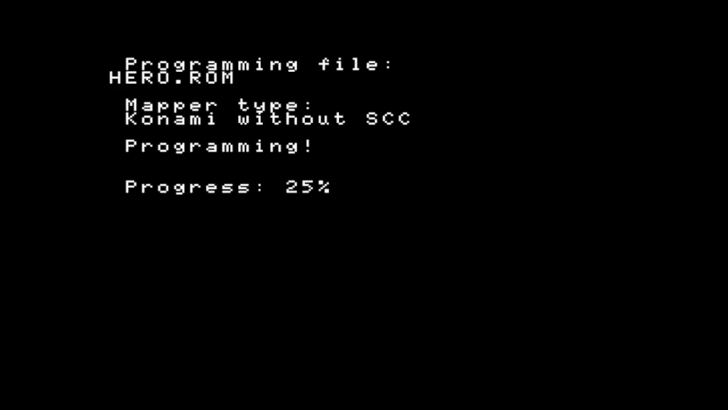
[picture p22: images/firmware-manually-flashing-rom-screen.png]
[](images/firmware-manually-flashing-rom-screen.png)

Once the flashing process finishes the RISKYMSX firmware will reboot the MSX computer and the flashed ROM will load.

## General troubleshooting.

If no LEDS are on during power up, You have issues with power lines or shorts.
If during power up and button pressed no LEDs are flashing your MPU doesn't start at all.
If you can download ROM to cart but MSX doesn't load data from cart then you have issues wih soldering of ADDRESS, DATA or BUS lines.

## Compatibility

The RISKYMSX cartridge has been tested on the following MSX computers:

| **Model** | **RISKYMSX** |
|---|---|
| Sony MSX HB-101P | OK |
| Sony MSX HB-501F | OK |
| Toshiba MSX HX-10 | OK |
| Philips MSX2 VG-8235 | OK |
| Panasonic MSX2+ FS-A1WSX | OK |
| Omega MSX2+ | OK |
| Tides Rider MSX2+ | OK |
| TFMSX Rev 1 MSX2+ | OK |
| TFMSX Rev 2 MSX2+ | OK |
| MSXVR | `NOK` |

Other MSX compatible computers will probably work too, but have not been specifically tested.

## Enclosures

### Acrylic Enclosure

You can complete your RISKYMSX cartridge with an [acrylic enclosure](https://github.com/herraa1/msx-riskymsx-enclosure) suitable for all RISKYMSX cartridge board revisions.

[](https://github.com/herraa1/msx-riskymsx-enclosure)

### 3D Printed Enclosure

Another option for closing your RISKY MSX Cartridge is following project  [Enclosure](https://github.com/rafaelan00/RISKYMSX-Enclosure)

rafaelanenclosure

## Acknowledgments

The following people contributed to this project and supported me with technical aspects of this project.
* Terrible Fire
* cnlohr 
* NYYRIKKI
* Aoineko
* BG Ollie
* MadHacker

Testing team:
* PhilC
* Higgy
* ahmsx
* Hee-Bong An
  
Thank you very much for your support.

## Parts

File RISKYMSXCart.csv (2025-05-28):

Reference | Value | Footprint | Qty
C1 | 100nF | 1206 | 1
C13 | 1uF | 1206 | 1
C3,C2,C4,C5,C6,C8,C9,C10,C11,C19 | 100nF | 603 | 10
C7 | 100nF | 1206 | 1
C18 | 1uF | 603 | 1
C12,C20 | 4.7uF | 603 | 2
C17,C14 | 1nF | 603 | 2
D1,D5 | LED | LED_SMD:LED_0805_2012Metric_Pad1.15x1.40mm_HandSolder | 2
F2 | 500MA | Fuse:Fuse_1206_3216Metric_Pad1.42x1.75mm_HandSolder | 1
IC8 | LM1117MPX-3.3 | tfcart:SOT223 | 1
J7 | USB_1 | Connector_USB:USB_A_CONNFLY_DS1095-WNR0 | 1
R1,R2,R4,R9,R10 | 10k | 603 | 2
R3,R5 | 220ohm | 603 | 2
U1 | CH32V303VCT6 | Package_QFP:LQFP-100_14x14mm_P0.5mm | 1
U2 | MCP6001-OT | Package_TO_SOT_SMD:SOT-23-5 | 1

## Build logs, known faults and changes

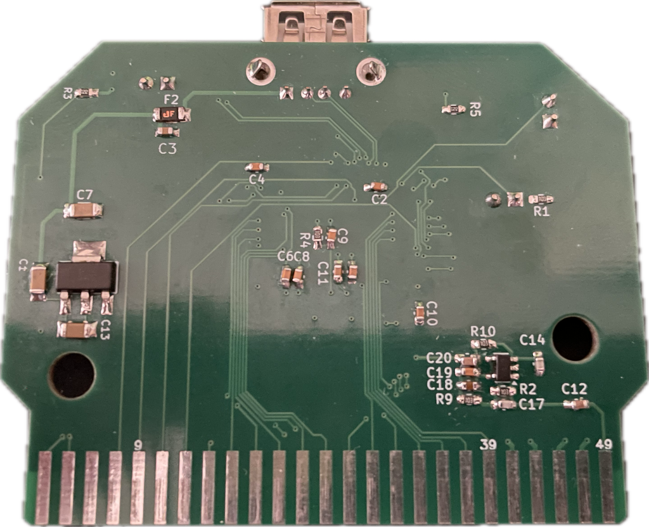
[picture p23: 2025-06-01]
images/RISKYMSXCart-Rev2.1-back-populated-1024px.png

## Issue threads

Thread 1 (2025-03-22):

need BOM

rafaelan00, 2025-03-22:
Hi. There is no BOM for PCB Rev.2

arkadiuszmakarenko, 2025-03-22:
I will try to find time to update BOM in next day or two.

arkadiuszmakarenko, 2025-03-22:
Done BOM updated

Closed 2025-03-22.

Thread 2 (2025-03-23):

Y1 missing in the BOM

rafaelan00, 2025-03-23:
Thank you for your BOM update. But there is no information about Y1. And The value of Fuse.

arkadiuszmakarenko, 2025-03-23:
Y1 is not needed.
Flash button is not needed either.

I personally use 500ma fuses, but you should be ok with much lower values.

Closed 2025-03-23.

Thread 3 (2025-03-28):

SCC sound not working

rafaelan00, 2025-03-28:
pcb rev2 and 2.1.6 firmware.
SCC sound is not working.
and ASCII16 mapper rom is not working either. konami mapper rom is working good. other megarom mapper is not tested yet.
J8 jumper is what for?

arkadiuszmakarenko, 2025-03-28:
J8 is for bypassing amplification circuit.
It is to help troubleshoot issues with SCC.
Do you have picture of your build round opamp.
I have tested it on F1 Sprint, Nemesis 2, 3 and Space Manbow.

ASCII16 was tested on Fantasy Zone 2.

What ROM and mapper did you use to test KONAMI with SCC (EN), and ASCII16?

I will try to record video with above mappers and SCC emulation later today.

rafaelan00, 2025-03-28:
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
J8 was not helped to me.
I have tested SCC(EN) with salamander and space manbow. Ascii16 with aleste and zanac ex enhanced.
I have tested it with OMEGA MSX, panasonic a1gt and daewoo cpc-400.
It works only with omega.
In the case of panasonic a1gt and daewoo cpc-400, they are not booted with risky msx at all.

arkadiuszmakarenko, 2025-03-28:
JP1 should be open not closed.

Sorry J8 is debug and programming interface

This cart was tested on Toshiba HX-10, TFMSX, Panasonic FS-A1. So far I never had complete no-boot report.

Ps Where are you based?

arkadiuszmakarenko, 2025-03-28:
Stability of ASCII16 is not great, I must have went too far with optimisations.
I will try to make it better, I guess it was long time since I tested this mapper

rafaelan00, 2025-03-29:
Now the machines boot with the cart. Maybe JP1 was the problem.
Still scc not working.
I appreciate your work.
PS. I'm based in Korea.

arkadiuszmakarenko, 2025-03-29:
SCC - I would suggest to take all opamp bits (U2,c14,R2,r9) off the board, close j1 and temporarily remove C12 and bridge pads.

This way you should get very faint SCC sound.
It is to isolate the issue with SCC.
If there is still nothing you would need to look for bridges near the main chip.

I will retest the SCC today as well just in case.

rafaelan00, 2025-03-29:
After remove all opamp parts, I've got the very faint scc sound.
Now what should I do?

arkadiuszmakarenko, 2025-03-29:
This is promising, so your issue is with amplification.

Absolute minimum circuit would be J1 open, opamp and 2x resistors (10K). Instead of caps just bridge those pads.

If this doesn't work I would look at Opamp. It may be wrong type, model pinout. There are different pin configurations of MCP6001.

rafaelan00, 2025-03-29:
Yes, you are right. Maybe I did order different model. Could you let me know the exact model number? I ordered it from digikey, but there are lots of model number of mcp6001.

arkadiuszmakarenko, 2025-03-29:
I use this

https://a.aliexpress.com/_EyxPoCs

rafaelan00, 2025-03-29:
I did replace pinout and now SCC sound works now.
I will wait next firmware for other rom mapper.
Thank you very much!

arkadiuszmakarenko, 2025-03-29:
@rafaelan00 Make sure you have caps in place. They are there to block DC. Those should  be good quality 4.7uF

rafaelan00, 2025-03-29:
Which one?

arkadiuszmakarenko, 2025-03-29:
C12, C14

rafaelan00, 2025-05-21:
Is it possible to use this cart as a external SCC cart for sofarun?

Closed 2025-03-29.

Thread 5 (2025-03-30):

Reboot issue

rafaelan00, 2025-03-30:
The cart flashed mega roms does not reboot with reset button. Kilo roms fine.
If I want to reboot during playing games, I have to power off and on. If I use reset button, the computer does not boot. Just black screen.

arkadiuszmakarenko, 2025-03-30:
There is already routine looking for reset, and should reboot cart when reset line changes.
Could you check if LEDs are changing at the reboot?

Ps
I don't  have MSX with reset button,so can't test myself.

arkadiuszmakarenko, 2025-03-30:
Another issue might be that reset is happening too fast.
Cart needs a little bit of time to set itself up after reboot.
Next possible one could you hold GRAPH at the reboot to check if LEDS change?

rafaelan00, 2025-03-30:
I did not solder the leds yet. But after black screen, another reset button calls basic screen. Repeat reset, basic screen. The cart is not working.

arkadiuszmakarenko, 2025-03-30:
I will have a look if this can be fixed.

arkadiuszmakarenko, 2025-03-30:
I have added reset button to my TFMSX, and I can't fully replicate the issue.

When hitting RESET LEDs should turn OFF and it should go to last game.

It doesn't allow go to flash terminal, which is what I would expect.

arkadiuszmakarenko, 2025-03-30:
I have added some change in v2.1.7 that might help.
It is hard to see what is happening on your MSX exactly.

rafaelan00, 2025-03-30:
v2.1.7 firmware solves the issue. Thank you.
But Ascii16 issue is still.

arkadiuszmakarenko, 2025-03-30:
I can run both titles on my msx2.
What about other ASCII16 games are you able to run any?

rafaelan00, 2025-03-30:
I've tested Aleste, Xevious, Zanac_EX, Fantasy zone 2 and different revision of them. None of them work properly. Some of them not boot, others boot but freezing.
ASCII8 version of Zanac_EX runs well.

arkadiuszmakarenko, 2025-03-30:
Do you know any MSX1 ASCII16 game?

rafaelan00, 2025-03-30:
The cart flashed ASCII16 roms is not working with main slots. But it works very well with a slot expander. I don't know why.
I have tested the cart with 4 slot expander, and it works with all kind of mappers.

arkadiuszmakarenko, 2025-03-30:
Hmmmm....
This is unexpected.

rafaelan00, 2025-03-30:
I tested more with other machines.(A1GT, CPC-400)
They works with main slot. Only OMEGA MSX works with slot expander.

arkadiuszmakarenko, 2025-03-30:
Should I continue looking for a fault or can I close this Issue?

rafaelan00, 2025-03-30:
You can close the issue. Thank you so much.

arkadiuszmakarenko, 2025-04-02:
Thank you for your feedback.

rafaelan00, 2025-05-29:
The cart flashed ASCII16 roms is working now in OMEGA's main slots with 3.1.0 firmware.

Closed 2025-03-31.

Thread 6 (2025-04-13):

File index not reset between pages when navigating

GadgetUK164, 2025-04-13:
If you create folders A to Z (26 of them) in the USB drive.  Create a couple of folders in the Z folder.  Navigate down to the 2nd page to display the Z folder, navigate into it - the screen will be blank (the two folders inside the Z folder are not shown), the code is looking at "page 2" of the Z folder, when there's only 1 page which should list the 2 folders that exist in there.

I guess the "page index" pointer is not getting reset when navigating into sub directories.

Closed 2025-04-20.

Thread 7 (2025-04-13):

The Rx + Tx Jumper Not Working (Default to 8 char filenames)

GadgetUK164, 2025-04-13:
Just a reminder this is currently not working, it would be cool if it did default using that jumper.

Alternatively, maybe it could be changed to come from a config file on the USB stick?  Might be easier and gives you more flexibility for any other optional settings?

rafaelan00, 2025-04-17:
same problem

arkadiuszmakarenko, 2025-04-17:
I have used those pins to measure SCC frequency, and forgot to revert use of it to short names.
I will add it back in next firmware.

arkadiuszmakarenko, 2025-04-20:
I have fixed this (I hope) in 2.1.8

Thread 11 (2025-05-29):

In Application Programming - Investigation

arkadiuszmakarenko, 2025-05-29:
Allow to flash new device firmware from application itself.

arkadiuszmakarenko, 2025-05-29:
I need to find a way of flashi

arkadiuszmakarenko, 2025-06-06:
I can't jump to flashed firmware without crashing the chip.

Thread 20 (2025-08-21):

Is 512kb planned?

RebelliousX, 2025-08-21:
Hello, and thank you for your great work 👍🏻

The reason I am asking is because Metal Gear 2 is 512KB. Is there a planned upgrade with different board design and chip to support that?
Maybe Raspberry Pi 2350?

Current board is good but a little complicated for soldering (at least for my low skills, lol) too many solder points, caps,
resistors and the RISC-V chip. I tried to let JLCPCB to do the assembly and they wanted $350 (with tariffs, tax and shipping) for 5 qty minimum.
That is insane. And JLCPCB don't even have Pin headers (out of stock). Bare boards around $35 immersion gold ENIG for the gold fingers though.

Are those pin headers optional (if I don't solder them)?

I know the RISC-V is good, and price at this point does not matter for 1 chip, but if we are talking about price, it is more expensive than RP2350 and the latter has 16MB flash rom.

Did you see [MSX Picoverse](https://github.com/denjhang/msx-picoverse)?

arkadiuszmakarenko, 2025-08-21:
This project was designed to provide ultra budget device that provides SSC emulation.
Meanwhile I wanted to learn a little about RISCV assembly and few other things related to that processor.

It is very unlikely that I will use other family chips, as I would need to start design and learning from scratch, without deep understanding about what timings that chip is capable of. Personally I am not interested in this kind of project as I would need to spend close to 100h.
As interest in current project is very low, I can't justify time investment of this level to design.

I was toying with idea to adapt project to WCH CH32H417 , but it really depends on price targets and some other details. This chip was not yet released, but should be in near future.

RebelliousX, 2025-08-21:
Thank you. I hope you don't abandon this project at least. You are the only one who still develop open source and low-cost solution cartridge board for the MSX.

So, it doesn't seem we will be able to get Metal Gear 2 running using this board unfortunately since it is 512KB rom file 😔

Besides SCC, is SCC+ emulation also supported?

I just ordered 5 PCBs from JLCPCB for around $20, I will try to solder the components by hand. I have never done this, I watched lots of youtube videos about soldering, lol.

RebelliousX, 2025-08-21:
Thanks a million 👍🏻 You are very helpful, I really appreciate it, hopefully everything will be okay when I build the board. That is why I ordered 5 PCBs with over 5 of everything else except the RISC-V, I just ordered 5 of them. Just in case I mess up something 😁 hopefully not.

RebelliousX, 2025-08-21:
I will, thank you 🤗

I ordered bunch of stuff from Mouser, Aliexpress and LCSC Electronics (for CH32V307VCT6). It might take 10 days or so.

I have USB-A, Male-to-Male cable which I used to flash firmware for Nvidia Shield TV, so that comes in handy to flash firmware for RiskyMSX I think. Does that mean I don't need to use the pin headers?

And if I can't build it (God forbid), I will "buy" a spare from you if you don't mind 👍🏻

arkadiuszmakarenko, 2025-08-21:
WCH has official store on AliExpress. CH32V303 which is cheaper and from official sources.

Better buy official WCH Link for programming

Closed 2025-08-21.

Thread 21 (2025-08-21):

Not all USB drives are recognised

arkadiuszmakarenko, 2025-08-21:
I got some reports that some USB Drives don't work well with this board.
I have the fix but I am now looking for drives that have issues with RISKYMSX to confirm that this fix covers most of them.

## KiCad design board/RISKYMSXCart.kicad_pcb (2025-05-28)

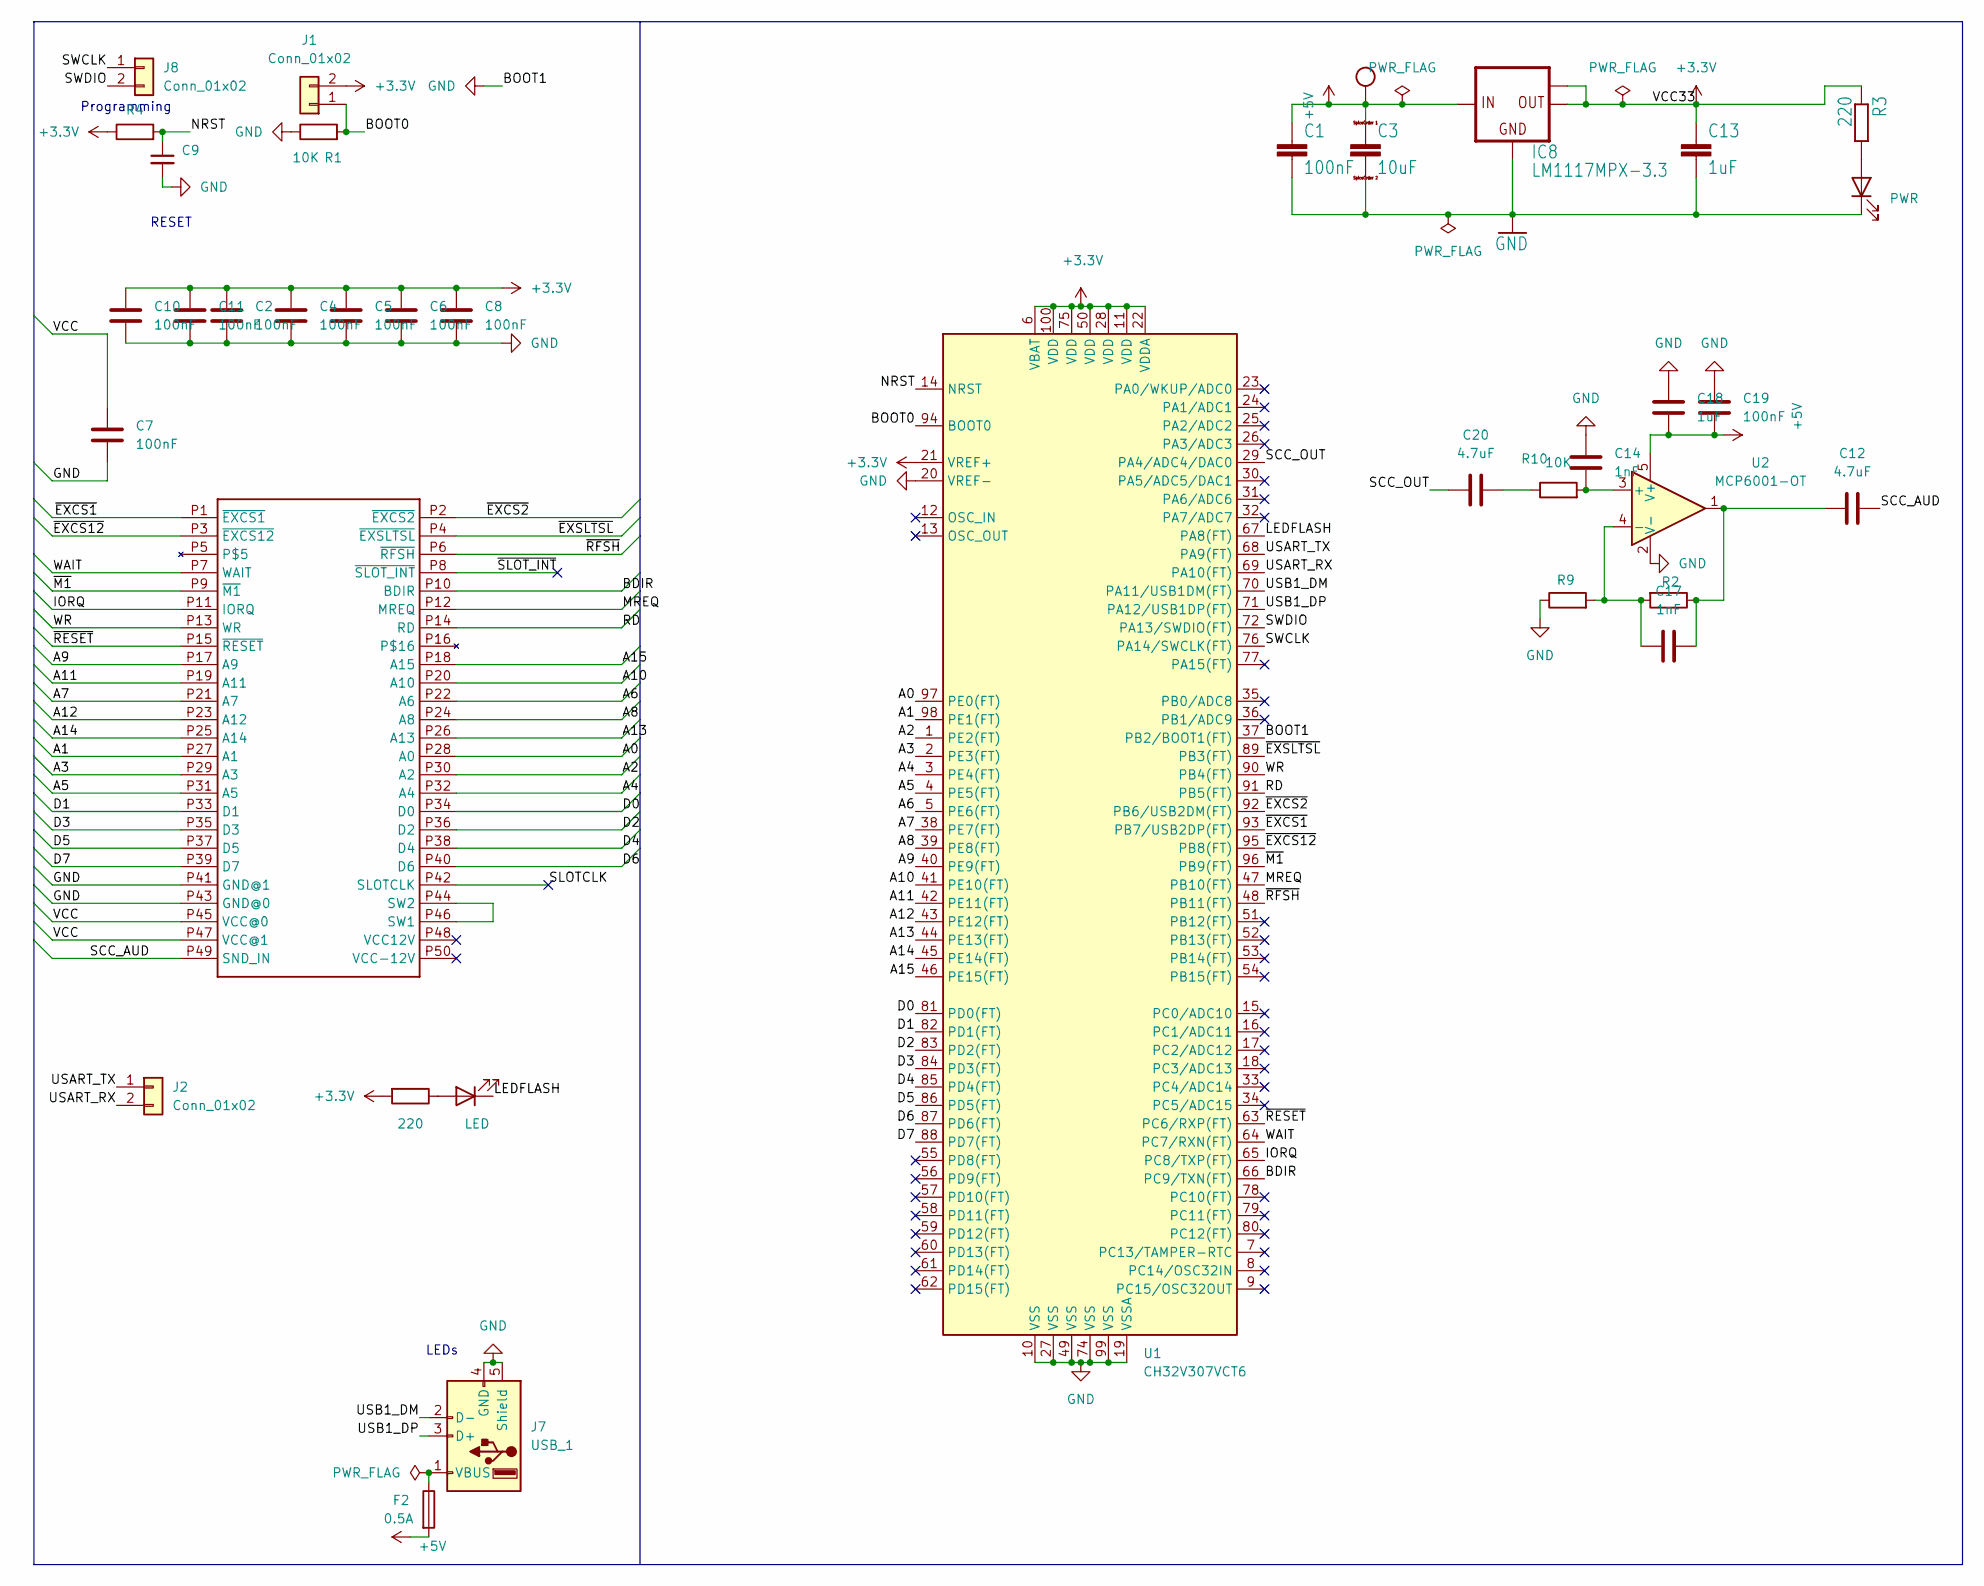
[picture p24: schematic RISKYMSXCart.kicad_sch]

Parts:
C1: 100nF; C1206
C2, C4, C5, C6, C8, C10, C11, C19: 100nF; C_0603_1608Metric_Pad1.08x0.95mm_HandSolder
C3: 10uF; C0603
C7: 100nF; C_1206_3216Metric_Pad1.33x1.80mm_HandSolder
C9: 100nF; C_0603_1608Metric_Pad1.08x0.95mm_HandSolder; LCSC C14663
C12, C20: 4.7uF; C_0603_1608Metric_Pad1.08x0.95mm_HandSolder
C13: 1uF; C1206
C14, C17: 1nF; C_0603_1608Metric_Pad1.08x0.95mm_HandSolder
C18: 1uF; C_0603_1608Metric_Pad1.08x0.95mm_HandSolder
CN1: MSX_CART
D1: LED; LED_0805_2012Metric_Pad1.15x1.40mm_HandSolder
D5: PWR; LED_0805_2012Metric_Pad1.15x1.40mm_HandSolder
F2: 0.5A; Fuse_1206_3216Metric_Pad1.42x1.75mm_HandSolder
IC8: LM1117MPX-3.3; SOT223
J1, J2, J8: Conn_01x02; PinHeader_1x02_P2.54mm_Vertical
J7: USB_1; USB_A_CONNFLY_DS1095-WNR0
R1, R2, R4, R9, R10: 10K; R_0603_1608Metric_Pad0.98x0.95mm_HandSolder
R3: 220; R0603
R5: 220; R_0603_1608Metric_Pad0.98x0.95mm_HandSolder
U1: CH32V307VCT6; LQFP-100_14x14mm_P0.5mm
U2: MCP6001-OT; SOT-23-5

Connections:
+3.3V: C2.1, C4.1, C5.1, C6.1, C8.1, C10.1, C11.1, C13.1, IC8.2 (OUT), IC8.TAB (OUT1), J1.2, R3.1, R4.1, R5.2, U1.6 (VBAT), U1.11 (VDD), U1.21 (VREF+), U1.22 (VDDA), U1.28 (VDD), U1.50 (VDD), U1.75 (VDD), U1.100 (VDD)
+5V: C1.1, C3.1, C7.1, C18.2, C19.2, CN1.P45 (VCC@0), CN1.P47 (VCC@1), F2.2, IC8.3 (IN), U2.5 (V+)
/A0: CN1.P28 (A0), U1.97 (PE0(FT))
/A1: CN1.P27 (A1), U1.98 (PE1(FT))
/A2: CN1.P30 (A2), U1.1 (PE2(FT))
/A3: CN1.P29 (A3), U1.2 (PE3(FT))
/A4: CN1.P32 (A4), U1.3 (PE4(FT))
/A5: CN1.P31 (A5), U1.4 (PE5(FT))
/A6: CN1.P22 (A6), U1.5 (PE6(FT))
/A7: CN1.P21 (A7), U1.38 (PE7(FT))
/A8: CN1.P24 (A8), U1.39 (PE8(FT))
/A9: CN1.P17 (A9), U1.40 (PE9(FT))
/A10: CN1.P20 (A10), U1.41 (PE10(FT))
/A11: CN1.P19 (A11), U1.42 (PE11(FT))
/A12: CN1.P23 (A12), U1.43 (PE12(FT))
/A13: CN1.P26 (A13), U1.44 (PE13(FT))
/A14: CN1.P25 (A14), U1.45 (PE14(FT))
/A15: CN1.P18 (A15), U1.46 (PE15(FT))
/BDIR: CN1.P10 (BDIR), U1.66 (PC9/TXN(FT))
/BOOT0: J1.1, R1.2, U1.94 (BOOT0)
/D0: CN1.P34 (D0), U1.81 (PD0(FT))
/D1: CN1.P33 (D1), U1.82 (PD1(FT))
/D2: CN1.P36 (D2), U1.83 (PD2(FT))
/D3: CN1.P35 (D3), U1.84 (PD3(FT))
/D4: CN1.P38 (D4), U1.85 (PD4(FT))
/D5: CN1.P37 (D5), U1.86 (PD5(FT))
/D6: CN1.P40 (D6), U1.87 (PD6(FT))
/D7: CN1.P39 (D7), U1.88 (PD7(FT))
/IORQ: CN1.P11 (IORQ), U1.65 (PC8/TXP(FT))
/LEDFLASH: D1.1 (K), U1.67 (PA8(FT))
/MREQ: CN1.P12 (MREQ), U1.47 (PB10(FT))
/NRST: C9.1, R4.2, U1.14 (NRST)
/RD: CN1.P14 (RD), U1.91 (PB5(FT))
/SCC_AUD: C12.2, CN1.P49 (SND_IN)
/SCC_OUT: C20.1, U1.29 (PA4/ADC4/DAC0)
/SLOTCLK: CN1.P42 (SLOTCLK)
/SWCLK: J8.1, U1.76 (PA14/SWCLK(FT))
/SWDIO: J8.2, U1.72 (PA13/SWDIO(FT))
/USART_RX: J2.2, U1.69 (PA10(FT))
/USART_TX: J2.1, U1.68 (PA9(FT))
/USB1_DM: J7.2 (D-), U1.70 (PA11/USB1DM(FT))
/USB1_DP: J7.3 (D+), U1.71 (PA12/USB1DP(FT))
/WAIT: CN1.P7 (WAIT), U1.64 (PC7/RXN(FT))
/WR: CN1.P13 (WR), U1.90 (PB4(FT))
/~EXCS1: CN1.P1 (~EXCS1), U1.93 (PB7/USB2DP(FT))
/~EXCS2: CN1.P2 (~EXCS2), U1.92 (PB6/USB2DM(FT))
/~EXCS12: CN1.P3 (~EXCS12), U1.95 (PB8(FT))
/~EXSLTSL: CN1.P4 (~EXSLTSL), U1.89 (PB3(FT))
/~M1: CN1.P9 (~M1), U1.96 (PB9(FT))
/~RESET: CN1.P15 (~RESET), U1.63 (PC6/RXP(FT))
/~RFSH: CN1.P6 (~RFSH), U1.48 (PB11(FT))
/~SLOT_INT: CN1.P8 (~SLOT_INT)
GND: C1.2, C2.2, C3.2, C4.2, C5.2, C6.2, C7.2, C8.2, C9.2, C10.2, C11.2, C13.2, C14.2, C18.1, C19.1, CN1.P41 (GND@1), CN1.P43 (GND@0), D5.1 (K), IC8.1 (GND), J7.4 (GND), J7.5 (Shield), R1.1, R9.1, U1.10 (VSS), U1.19 (VSSA), U1.20 (VREF-), U1.27 (VSS), U1.37 (PB2/BOOT1(FT)), U1.49 (VSS), U1.74 (VSS), U1.99 (VSS), U2.2 (V-)
unnamed: C12.1, C17.2, R2.1, U2.1
unnamed: C20.2, R10.1
unnamed: CN1.P44 (SW2), CN1.P46 (SW1)
unnamed: D1.2 (A), R5.1
unnamed: D5.2 (A), R3.2
unnamed: F2.1, J7.1 (VBUS)
unnamed: C14.1, R10.2, U2.3 (+)
unnamed: C17.1, R2.2, R9.2, U2.4 (-)

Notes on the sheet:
RESET
Programming
LEDs

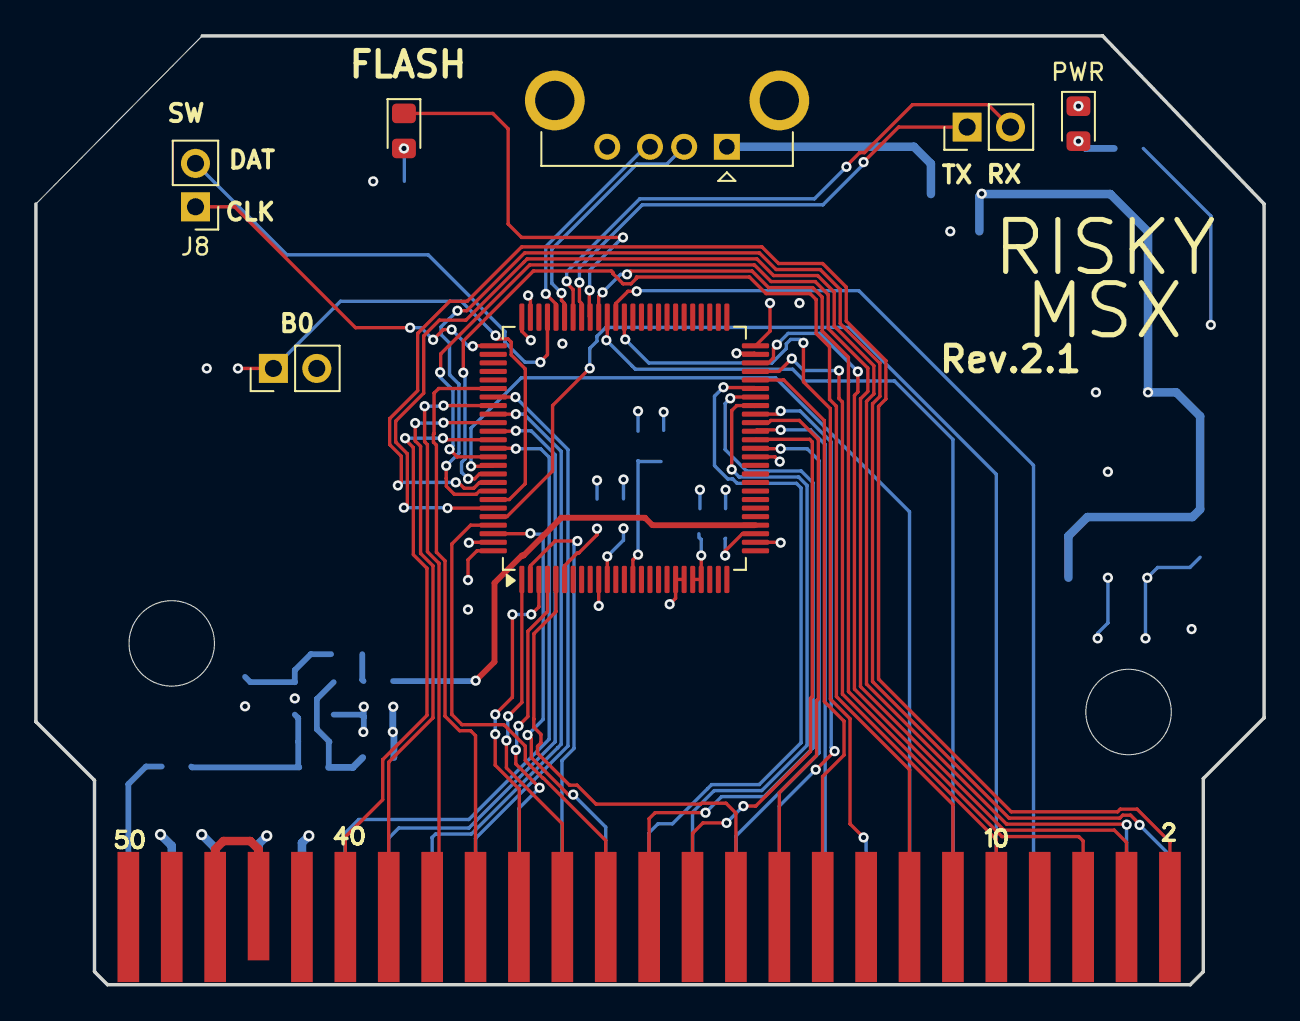
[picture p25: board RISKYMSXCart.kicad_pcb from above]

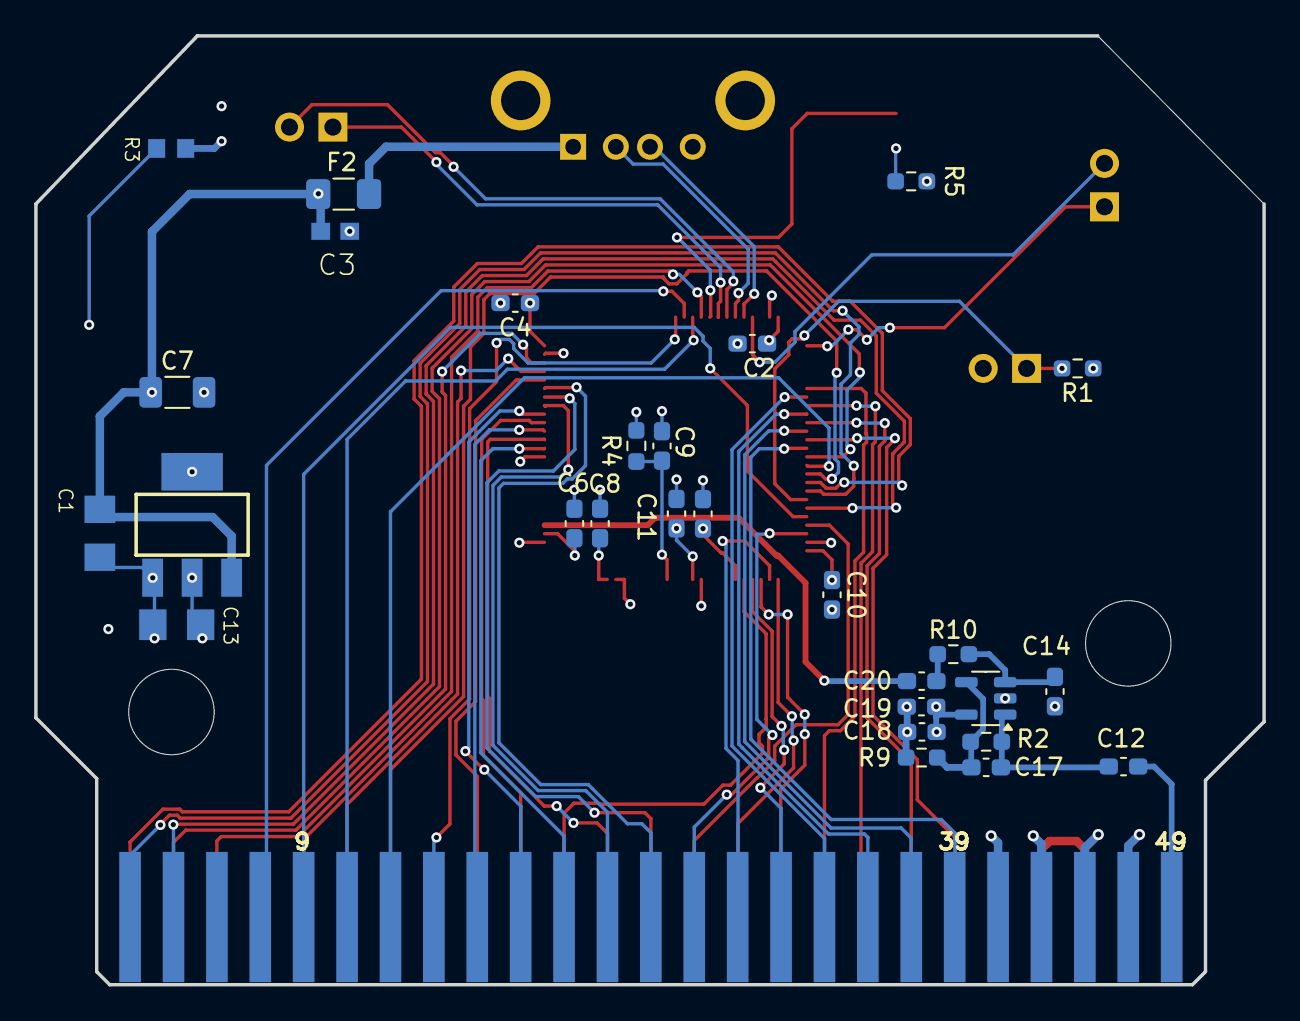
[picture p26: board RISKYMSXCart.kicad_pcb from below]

Board: 4 copper layers, 71.9 x 55.5 mm, 38 parts (28 on the bottom side), 59 nets.

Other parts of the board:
@HOLE1, @HOLE1#2: (no value)

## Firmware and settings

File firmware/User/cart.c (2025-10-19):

#include "cart.h"


// GPIOE Pins    0 - 16      Address
// GPIOD Pins    0 - 8       Data

// GPIOB Pin     3           SLT   0x0008
// GPIOB Pin     4           WR    0x0010
// GPIOB Pin     5           RD    0x0020

// GPIOB Pin     6           CS2   0x0040
// GPIOB Pin     7           CS1   0x0080
// GPIOB Pin     8           CS12  0x0100

// GPIOB Pin     9           M1    0x0200
// GPIOB Pin     10          MREQ  0x0400
// GPIOB Pin     11          RESH  0x0800

// GPIOC Pin     6           RESET 0x0040
// GPIOC Pin     7           WAIT  0x0080
// GPIOC Pin     8           IORQ  0x0100
// GPIOC Pin     9           BDIR  0x0200

#pragma GCC push_options
#pragma GCC optimize("Ofast")

extern CircularBuffer scb;
extern CircularBuffer icb;
extern CircularBuffer cb;
extern uint32_t enableTerminal;

static const uint8_t msxterm[213] = {
    'A',
    'B',
    '&',
    '@',
    0,
    0,
    0,
    0,
    0,
    0,
    0,
    0,
    0,
    0,
    0,
    0,
    'R',
    'I',
    'S',
    'K',
    'Y',
    '_',
    'B',
    'O',
    'O',
    'T',
    0,
    '1',
    '.',
    '0',
    0,
    0,
    '>',
    04,
    '2',
    0376,
    0177,
    0311,
    '!',
    '3',
    '@',
    021,
    0,
    0340,
    01,
    0232,
    0,
    0325,
    0355,
    0260,
    0311,
    '>',
    06,
    0315,
    'A',
    01,
    0346,
    04,
    '2',
    0376,
    0177,
    ' ',
    'Y',
    '>',
    ' ',
    '2',
    0257,
    0363,
    '!',
    017,
    0,
    '"',
    0352,
    0363,
    '"',
    0351,
    0363,
    '>',
    01,
    0315,
    '_',
    0,
    '!',
    0315,
    '@',
    021,
    0,
    '8',
    01,
    010,
    0,
    0315,
    0134,
    0,
    '>',
    010,
    '!',
    03,
    033,
    0315,
    'M',
    0,
    ':',
    0377,
    0177,
    0376,
    03,
    '(',
    '+',
    0376,
    04,
    '(',
    024,
    0247,
    0314,
    0217,
    0340,
    0304,
    0242,
    0,
    0315,
    0234,
    0,
    '(',
    0351,
    0315,
    0237,
    0,
    '2',
    0375,
    0177,
    030,
    0341,
    ':',
    0377,
    0177,
    '!',
    01,
    033,
    0315,
    'M',
    0,
    ':',
    0377,
    0177,
    '=',
    '-',
    0315,
    'M',
    0,
    030,
    0316,
    0315,
    0217,
    0340,
    0315,
    0217,
    0340,
    '*',
    0261,
    0366,
    021,
    0364,
    0377,
    031,
    0345,
    '^',
    '#',
    'V',
    '!',
    0243,
    '}',
    0347,
    0341,
    ' ',
    014,
    021,
    0204,
    0340,
    's',
    '#',
    'r',
    0311,
    0301,
    0341,
    0303,
    0204,
    '}',
    036,
    'R',
    0315,
    0261,
    0377,
    0307,
    0365,
    0373,
    '!',
    0236,
    0374,
    '~',
    0276,
    '(',
    0375,
    0361,
    0311,
    ' ',
    '0',
    '8',
    '<',
    '8',
    '0',
    ' ',
    0,
};

// MSX State bank offsets.
struct MSXState {
    uint32_t bankOffsets[16];
    uint32_t BusOn;
    uint32_t BusOff;
    uint32_t IRQLine3;
} state;

// global variables#
CartType type;
struct MSXState *state_pointer;
uint8_t *restrict cartpnt;
uint8_t *rampnt;
CircularBuffer *buf;
CircularBuffer *sbuf;
CircularBuffer *ibuf;

// Config Cart emulation hardware.
void Init_Cart() {

    state_pointer = &state;
    cartpnt = (uint8_t *)&__cart_section_start;
    rampnt = (uint8_t *)0x20007C00;
    buf = &cb;
    sbuf = &scb;
    ibuf = &icb;

    FLASH_Enhance_Mode (ENABLE);
    CART_CFG *cfg;
    uint8_t *restrict cfgpnt = (uint8_t *)&__cfg_section_start;
    cfg = (CART_CFG *)cfgpnt;
    type = cfg->CartType;

    uint8_t value = *rampnt;
    if (value != 1) {
        type = MSXTERMINAL;
    }
    *rampnt = 0;


    state_pointer->BusOn = 0x33333333;
    state_pointer->BusOff = 0x44444444;
    state_pointer->IRQLine3 = EXTI_Line3;

    switch (type) {
    case ROM16k:
        state_pointer->bankOffsets[0] = -0x4000;
        state_pointer->bankOffsets[1] = -0x8000;
        GPIO_WriteBit (GPIOA, GPIO_Pin_0, Bit_RESET);  // 1 - 0001
        NVIC_EnableIRQ (EXTI3_IRQn);
        SetVTFIRQ ((u32)RunCart16k, EXTI3_IRQn, 0, ENABLE);
        break;

    case ROM32k:
        state_pointer->bankOffsets[0] = -0x4000;
        GPIO_WriteBit (GPIOA, GPIO_Pin_0, Bit_RESET);  // 1 - 0001
        NVIC_EnableIRQ (EXTI3_IRQn);
        SetVTFIRQ ((u32)RunCart32k, EXTI3_IRQn, 0, ENABLE);
        break;
    case ROM48k:
        GPIO_WriteBit (GPIOA, GPIO_Pin_1, Bit_RESET);  // 2 - 0010
        NVIC_EnableIRQ (EXTI3_IRQn);
        SetVTFIRQ ((u32)RunCart48k, EXTI3_IRQn, 0, ENABLE);
        break;
    case KonamiWithoutSCC:
        GPIO_WriteBit (GPIOA, GPIO_Pin_0, Bit_RESET);  // 3 - 0011
        GPIO_WriteBit (GPIOA, GPIO_Pin_1, Bit_RESET);

        // configure initial banks state for Konami without SCC
        state_pointer->bankOffsets[2] = -0x4000;
        state_pointer->bankOffsets[3] = -0x8000;
        state_pointer->bankOffsets[4] = 0x0;
        state_pointer->bankOffsets[5] = 0x0;
        NVIC_EnableIRQ (EXTI3_IRQn);
        SetVTFIRQ ((u32)RunKonamiWithoutSCC, EXTI3_IRQn, 0, ENABLE);
        break;
    case KonamiWithSCC:
        SCC_Init();
        GPIO_WriteBit (GPIOA, GPIO_Pin_2, Bit_RESET);  // 4 - 0100
        state_pointer->bankOffsets[2] = -0x4000;
        state_pointer->bankOffsets[3] = -0x6000;
        state_pointer->bankOffsets[4] = -0x8000;
        state_pointer->bankOffsets[5] = -0xA000;

        NVIC_EnableIRQ (EXTI3_IRQn);
        NVIC_SetPriority (EXTI3_IRQn, 0);
        SetVTFIRQ ((u32)RunKonamiWithSCC, EXTI3_IRQn, 0, ENABLE);
        break;
    case KonamiWithSCCNOSCC:
        GPIO_WriteBit (GPIOA, GPIO_Pin_0, Bit_RESET);
        GPIO_WriteBit (GPIOA, GPIO_Pin_2, Bit_RESET);

        state_pointer->bankOffsets[2] = -0x4000;
        state_pointer->bankOffsets[3] = -0x6000;
        state_pointer->bankOffsets[4] = -0x8000;
        state_pointer->bankOffsets[5] = -0xA000;

        NVIC_EnableIRQ (EXTI3_IRQn);
        NVIC_SetPriority (EXTI3_IRQn, 0);
        SetVTFIRQ ((u32)RunKonamiWithSCCNOSCC, EXTI3_IRQn, 0, ENABLE);
        break;

    case ASCII8k:
        GPIO_WriteBit (GPIOA, GPIO_Pin_1, Bit_RESET);  //  6 - 0110
        GPIO_WriteBit (GPIOA, GPIO_Pin_2, Bit_RESET);

        // configure initial banks state for ASCII8K
        state_pointer->bankOffsets[0] = -0x4000;  // switch address 6000h  -0x4000;
        state_pointer->bankOffsets[1] = -0x6000;  // switch address 6800h  -0x6000;
        state_pointer->bankOffsets[2] = -0x8000;  // switch address 7000h  -0x8000;
        state_pointer->bankOffsets[3] = -0xA000;  // switch address 7800h  -0xA000;
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

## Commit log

2025-01-17 Release 1 - PCB Rev1, firmware v0.1
    [RISKYMSXCart-B_Cu.gbr, RISKYMSXCart-B_Mask.gbr, RISKYMSXCart-B_Paste.gbr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]
2025-01-25 Version 0.3 Stability fixes
    [cart.c]
2025-01-26 Mapper LEDs fix version v0.4.1
    [cart.c]
2025-02-06 Change from relative to absolute menu prints
2025-02-07 v0.6 Release Mapper change without reflashing (diag) Changes to KOMAMI WITH SCC DIS Changes to printfilename clearing buffer with 0x20 caused issues witgh longnames decoding
    [cart.c]
2025-02-10 remove volatile (those variable won't change in this IRQs)
    [cart.c]
2025-02-10 v0.7.3 remove second USB check. In case of issues hit button 1.
2025-02-12 v0.8.3 Konami with SCC cold boot fix
    [cart.c]
2025-02-12 Rev2 PCB
    [RISKYMSXCart-B_Cu.gbr, RISKYMSXCart-B_Mask.gbr, RISKYMSXCart-B_Paste.gbr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]
2025-02-16 v0.9 - Toggle Short/Longnames with 9 or TxRx Pin
2025-02-22 v0.10.0 Handle MSX Reset
    [main.c]
2025-02-25 Release 2.0 PCB and updated firmare for this PCB
2025-03-01 v2.02 sound glitch fix
    [cart.c]
2025-03-03 v2.1.1 GRAPH button entry to flash screens. Tidy up of DAC configuration - no need for DMA and TIM4. This could cause issues,so bteer simplpify it. Arrow as a pointer instead of visible cursor. Look 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
    [cart.c, main.c]
2025-03-09 Rev 2.1.3 SCC accuaracy fixes
    [cart.c, main.c]
2025-03-15 v2.5.1 enable DAC buffer. Rev1 boards compatible
2025-03-22 Initial version 2.1
    [RISKYMSXCart.kicad_pcb, RISKYMSXCart.kicad_sch]
2025-03-22 Rev2 BOM
    [RISKYMSXCart.csv]
2025-03-23 Update RISKYMSXCart.csv
    Update fuse value
    [RISKYMSXCart.csv]
2025-03-30 v2.1.7 ASCII16 Mapper fix Reset fix
    [cart.c, main.c]
2025-04-02 Rev2.1 Gerbers
    [RISKYMSXCart-B_Cu.gbr]
2025-04-20 v2.1.8 Rev2.1 PCB Design change BOM change https://github.com/arkadiuszmakarenko/RISKYMSX/issues/7 fix https://github.com/arkadiuszmakarenko/RISKYMSX/issues/6 fix FLashLED added.
    [RISKYMSXCart-B_Cu.gbr, RISKYMSXCart-B_Mask.gbr, RISKYMSXCart-B_Paste.gbr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]
2025-05-27 Specify confirmed values in BoM, schematic and PCB, fix minor csv bom issues, add .gitignore (#10)
    * schematic: add confirmed values for components with missing values
    * pcb: update values from schematic
    * kicad: add interactive BoM
    * add .gitignore
    * csv bom: fix duplicate C14
    * csv bom: match footprint of C7 in BoM to that of the PCB
    * csv bom: fix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
    [RISKYMSXCart.csv, RISKYMSXCart.kicad_pcb, RISKYMSXCart.kicad_sch]
2025-05-30 v3.1.2 flush button to prevent sticky keyboard presses
2025-06-16 readme: add section for enclosures (#17)
2025-09-21 Small code cleanups and file navigation enhancements (#22)
    * consolidate auto programming
    * consolidate filesystem mount
    * consolidate file array size constant
    * improve file menu navigation
    ---------
2026-10-15 Tidy .gitignore for toolchain and build artifacts
    Root .gitignore additions:
    - board/.history/ KiCad local backups
    - out/ build-bootloader/ build-standalone/ build outputs
    - bootloader/obj/ bootloader/.mrs/ auto-generated under bootloader/
    - Bootloader.bin RISKYMSXCART.bin local prebuilt images at repo root
    (release artifact RISKYMSXCART_v3.3.0.bin stays tracked)
    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
